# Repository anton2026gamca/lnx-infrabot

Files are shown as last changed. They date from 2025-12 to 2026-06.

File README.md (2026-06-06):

# LNX InfraBot

An autonomous soccer robot for **RoboCup Junior** (Infrared/IR version) that seamlessly integrates hardware control and computer vision. The system uses a Raspberry Pi for advanced vision processing and control logic, while a Teensy microcontroller manages real-time motor and sensor operations.

---

## Project Overview

**LNX-InfraBot** is a competition-ready robot featuring:

- **RoboCup Junior Compliance**: Designed for the Infrared competition category
- **Advanced Computer Vision**: Real-time image processing with OpenCV and NumPy for ball and goal detection
- **Robust Hardware Control**: Motor and sensor integration via Teensy microcontroller
- **Web Dashboard Integration**: Seamless connection with [lnx-dashboard](https://github.com/anton2026gamca/lnx-dashboard) for calibration, remote monitoring, and control
- **Reliable Serial Communication**: High-speed protocol between Raspberry Pi and Teensy

---

## Hardware Components

### Raspberry Pi
- Runs main control software (Python)
- Interfaces with PiCamera2 for vision input
- Hosts FastAPI web server
- Communicates with Teensy via serial connection

### Teensy Microcontroller
- Real-time motor and sensor control
- Manual control switches and status LEDs
- High-speed serial communication (84 kbaud, targeting 120 messages/second)

### 3D Printed Components
- Custom chassis and parts (see `hardware/3D design/`)

---

## Project Structure

```
lnx-infrabot/
├── raspberrypi/             # Raspberry Pi software
│   ├── main.py              # Entry point
│   ├── requirements.txt     # Python dependencies
│   ├── robot.service        # Systemd service file
│   └── robot/               # Main robot package
│       ├── config.py        # Configuration management
│       ├── robot.py         # Core robot control
│       ├── api/             # FastAPI web server
│       ├── hardware/        # Hardware interfaces
│       ├── vision/          # Computer vision processing
│       ├── logic/           # Control logic and algorithms
│       ├── calibration/     # Calibration utilities
│       ├── multiprocessing/ # Concurrent process management
│       └── utils/           # Utility functions
├── teensy/                  # Teensy firmware
│   ├── teensy.ino           # Main Teensy sketch
│   ├── sketch.yaml          # Arduino sketch configuration
│   ├── structures.txt       # Data structure definitions
│   └── test_programs/       # Testing utilities
├── hardware/                # Hardware designs and documentation
│   └── 3D design/           # 3D printable robot parts
├── CONTRIBUTING.md          # Contribution guidelines
└── README.md                # This file
```

---

## Installation

### Raspberry Pi Setup

- **Prerequisites:**
    - **Raspberry Pi 5** with **Raspberry Pi OS Lite** installed

1. **Configure UART, I2C and Camera**  
   Edit `/boot/firmware/config.txt` using a text editor like `nano`:
   ```sh
   sudo nano /boot/firmware/config.txt
   ```
   Add or update the following lines:
   ```txt
   # UART 
   dtoverlay=uart0-pi5

   # Camera
   camera_auto_detect=0
   dtoverlay=imx708,cam0
   dtoverlay=imx708,cam1
   ```
   After editing, press `Ctrl+X` and then `Y` to exit and save.

   Enable I2C:
   ```bash
   sudo raspi-config
   ```
   Go to `Interface Options` -> `I2C`, select `Yes` and press `Enter`

   ```bash
   sudo reboot
   ```

   For more info about the camera, see the [official documentation](https://docs.arducam.com/Raspberry-Pi-Camera/Native-camera/12MP-IMX708/#software-configuration)

2. **Install Dependencies**
   ```bash
   sudo apt update
   sudo apt install git python3.13-dev libcap-dev libgl1 libcamera-apps python3-libcamera i2c-tools python3-gpiozero python3-lgpio
   sudo apt install python3-picamera2 --no-install-recommends
   ```

3. **Clone the Repository**
   ```bash
   git clone --no-checkout https://github.com/anton2026gamca/lnx-infrabot
   cd lnx-infrabot
   git sparse-checkout init --cone
   git sparse-checkout set raspberrypi
   git checkout main
   ```

4. **Set Up Python Virtual Environment**
   ```bash
   cd raspberrypi
   python3 -m venv --system-site-packages .venv
   source .venv/bin/activate
   ```

5. **Install Python Dependencies**
   ```bash
   pip install -r requirements.txt
    ```

6. **Set Environment Variables**
   Create a `.env` file:
   ```
   AUTH_TOKEN=your-secure-token     # Defaults to `ooops` if not set
   ```

7. **Enable Auto-Start**
   ```bash
   sudo ln -s "$(pwd)/robot.service" /etc/systemd/system/
   sudo systemctl daemon-reload
   sudo systemctl enable robot
   sudo systemctl start robot
   ```

### Teensy Setup

1. Open `teensy/teensy.ino` in Arduino IDE
2. Install library dependency: **teensy4_i2c** by Richard Gemmell
3. Select Board: **Teensy 4.1**
4. Upload the sketch to your Teensy board

---

## Usage

### Web API & Dashboard

The robot exposes a FastAPI web server with WebSocket support for real-time communication.

Connect using the [lnx-dashboard](https://github.com/anton2026gamca/lnx-dashboard) for:
- Live camera feed with vision overlays
- Robot telemetry (motion, sensor data)
- Manual and autonomous control

---

## Contributing

See [CONTRIBUTING.md](CONTRIBUTING.md)

---

## Related Projects

- [lnx-dashboard](https://github.com/anton2026gamca/lnx-dashboard) — Web-based monitoring and control dashboard for LNX-InfraBot

---

## RoboCup Junior Information

LNX-InfraBot is designed for the **RoboCup Junior Soccer - Infrared (IR) League**. Learn more:
- [Official RoboCup Website](https://www.robocup.org/)

---

## License

See [LICENSE](LICENSE)

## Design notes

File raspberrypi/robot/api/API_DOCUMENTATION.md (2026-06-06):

# Robot API Documentation

## Overview

This is a comprehensive WebSocket/HTTP API for controlling and monitoring a robot with vision capabilities. The API uses **SocketIO** for real-time bidirectional communication and **FastAPI** as the HTTP server.

**Server Details:**
- Protocol: SocketIO (WebSocket with fallback)
- Authentication: Token-based (base64 encoded) via query parameter
- Max HTTP Buffer Size: 5 MB
- CORS: Enabled for all origins

---

## Table of Contents

1. [Authentication](#authentication)
2. [Real-time Events (Subscriptions)](#real-time-events-subscriptions)
3. [Sensor & State Queries](#sensor--state-queries)
4. [Robot Control (Mutations)](#robot-control-mutations)
5. [Calibration Procedures](#calibration-procedures)
6. [Bluetooth Communication](#bluetooth-communication)
7. [Video Streaming](#video-streaming)
8. [Profiling & Performance](#profiling--performance)

---

## Authentication

All WebSocket connections require authentication via a token passed in the query string:

```
ws://host:port/socket.io/?token=<BASE64_ENCODED_TOKEN>
```

The token is base64-encoded from the configured `AUTH_TOKEN`. If authentication fails, the connection is rejected with a log warning.

---

## Real-time Events (Subscriptions)

### `subscribe_updates`

Subscribe to state change notifications.

**Request:**
```typescript
{
  event: "subscribe_updates",
  data: {
    updates: {
      mode_changed?: boolean,
      goal_color_changed?: boolean,
      important_sensor_data_change?: boolean,
      new_logs?: boolean
    }
  }
}
```

**Response:**
```typescript
{
  status: "ok" | "error",
  message?: string,
  error?: string
}
```

**Emitted Events:**

**`mode_changed`** - Robot mode has changed
```typescript
{
  mode: "idle" | "manual" | "autonomous"
}
```

**`goal_color_changed`** - Target goal color changed
```typescript
{
  goal_color: "yellow" | "blue"
}
```

**`important_sensor_data_change`** - Critical sensor state changed (line, IR, or camera ball detection)
```typescript
{
  status: "ok",
  compass: {
    heading: number,
    pitch: number,
    roll: number
  },
  ir: {
    angle: number,
    distance: number,
    sensors: number[],
    status: string
  },
  camera_ball: {
    angle: number | null,
    distance: number | null,
    detected: boolean | null
  },
  line: {
    raw: number[],
    detected: boolean,
    thresholds: [[number, number], ...]
  },
  motors: {
    left: number,
    right: number
  },
  kicker: {
    charged: boolean,
    ready: boolean
  },
  running_state: {
    running: boolean,
    bt_module_enabled: boolean,
    bt_module_state: boolean,
    switch_state: boolean
  } | null,
  timestamp: number
}
```

**`new_logs`** - New log entries available
```typescript
{
  logs: Array<{
    id: number,
    level: string,
    message: string,
    timestamp: number
  }>
}
```

### `unsubscribe_updates`

Unsubscribe from all state change notifications.

**Request:**
```typescript
{
  event: "unsubscribe_updates",
  data: {}
}
```

**Response:**
```typescript
{
  status: "ok"
}
```

---

## Sensor & State Queries

### `get_sensor_data`

Get current sensor readings and hardware state.

**Request:**
```typescript
{
  event: "get_sensor_data",
  data: {}
}
```

**Response:**
```typescript
{
  status: "ok",
  compass: {
    heading: number,
    pitch: number,
    roll: number
  },
  ir: {
    angle: number,
    distance: number,
    sensors: number[],
    status: string
  },
  camera_ball: {
    angle: number | null,
    distance: number | null,
    detected: boolean | null
  },
  line: {
    raw: number[],
    detected: boolean,
    thresholds: [[number, number], ...]
  },
  motors: {
    left: number,
    right: number
  },
  kicker: {
    charged: boolean,
    ready: boolean
  },
  running_state: {
    running: boolean,
    bt_module_enabled: boolean,
    bt_module_state: boolean,
    switch_state: boolean
  } | null,
  timestamp: number
}
```

### `get_logs`

Retrieve log entries since a specific ID.

**Request:**
```typescript
{
  event: "get_logs",
  data: {
    since?: number  // Log ID to retrieve logs after (default: 0)
  }
}
```

**Response:**
```typescript
{
  status: "ok",
  logs: Array<{
    id: number,
    level: string,
    message: string,
    timestamp: number
  }>,
  last_id: number
}
```

### `get_mode`

Get current robot operation mode.

**Request:**
```typescript
{
  event: "get_mode",
  data: {}
}
```

**Response:**
```typescript
{
  status: "ok",
  mode: "idle" | "manual" | "autonomous"
}
```

### `get_motor_settings`

Get current motor control settings.

**Request:**
```typescript
{
  event: "get_motor_settings",
  data: {}
}
```

**Response:**
```typescript
{
  status: "ok",
  rotation_correction_enabled: boolean,
  line_avoiding_enabled: boolean,
  position_based_speed_enabled: boolean
}
```

### `get_goal_settings`

Get goal detection color and calibration ranges.

**Request:**
```typescript
{
  event: "get_goal_settings",
  data: {}
}
```

**Response:**
```typescript
{
  status: "ok",
  goal_color: "yellow" | "blue",
}
```

### `get_goal_color_calibration`

Get goal color calibration ranges used for goal detection.

**Request:**
```typescript
{
  event: "get_goal_color_calibration",
  data: {
    camera: "front" | "back"
  }
}
```

**Response:**
```typescript
{
  status: "ok"
  yellow_ranges: Array<{
    lower: [number, number, number],  // [H, S, V]
    upper: [number, number, number]   // [H, S, V]
  }>
  blue_ranges: Array<{
    lower: [number, number, number],  // [H, S, V]
    upper: [number, number, number]   // [H, S, V]
  }>
}
```

**HSV Range:**
- **H (Hue):** 0-179
- **S (Saturation):** 0-255
- **V (Value):** 0-255

### `get_goal_detection`

Get current goal detection result.

**Request:**
```typescript
{
  event: "get_goal_detection",
  data: {}
}
```

**Response:**
```typescript
{
  status: "ok",
  goal_detected: boolean,
  alignment: number,           // -1.0 to 1.0 (center alignment)
  goal_center_x: number | null,
  goal_area: number,
  distance_mm: number | null,  // may be null if not available
  goal_height_pixels: number,
  camera_yaw_deg: number,
  goals_by_color: {
    yellow: {
      goal_detected: boolean,
      alignment: number,
      goal_center_x: number | null,
      goal_area: number,
      distance_mm: number | null,
      goal_height_pixels: number,
      camera_yaw_deg: number,
    },
    blue: {
      goal_detected: boolean,
      alignment: number,
      goal_center_x: number | null,
      goal_area: number,
      distance_mm: number | null,
      goal_height_pixels: number,
      camera_yaw_deg: number,
    }
  },
  enemy_goal_color: "yellow" | "blue",
  own_goal_color: "yellow" | "blue",
}
```

### `get_position_estimate`

Get estimated robot position on the field.

**Request:**
```typescript
{
  event: "get_position_estimate",
  data: {}
}
```

**Response:**
```typescript
{
  status: "ok",
  x_mm: number | null,
  y_mm: number | null,
  confidence: number  // 0.0 to 1.0
}
```

### `get_detections`

Get detected objects, optionally filtered by camera.

**Request:**
```typescript
{
  event: "get_detections",
  data: {
    camera?: "front" | "back" | "both" // Default: "both"
  }
}
```

**Response:**
```typescript
{
  status: "ok",
  camera: "front" | "back" | "both",
  detections: {
    front?: Array<{
      object_type: string,
      x: number,
      y: number,
      width: number,
      height: number,
      confidence: number,
      color: [number, number, number], // [B, G, R]
      camera: "front" | "back" | null
    }>,
    back?: Array<{
      object_type: string,
      x: number,
      y: number,
      width: number,
      height: number,
      confidence: number,
      color: [number, number, number], // [B, G, R]
      camera: "front" | "back" | null
    }>
  }
}
```

### `get_ball_calibration`

Get current ball color calibration ranges.

**Request:**
```typescript
{
  event: "get_ball_calibration",
  data: {
    camera?: "front" | "back" // Default: "front"
  }
}
```

**Response:**
```typescript
{
  status: "ok",
  camera: "front" | "back",
  ranges: Array<{
    lower: [number, number, number],  // [H, S, V]
    upper: [number, number, number]   // [H, S, V]
  }>
}
```

### `get_goal_focal_length`

Get the focal length used for distance calculations.

**Request:**
```typescript
{
  event: "get_goal_focal_length",
  data: {
    camera?: "front" | "back" // Default: "front"
  }
}
```

**Response:**
```typescript
{
  status: "ok",
  camera: "front" | "back",
  focal_length_pixels: number
}
```

### `get_camera_settings`

Get current manual camera control values (persisted calibration values).

**Request:**
```typescript
{
  event: "get_camera_settings",
  data: {
    camera?: "front" | "back" | "both" // Default: "both"
  }
}
```

**Response:**
```typescript
{
  status: "ok",
  camera: "front" | "back" | "both",
  settings: {
    front?: {
      camera: "front",
      color_gains: [number, number], // [red_gain, blue_gain]
      exposure_time: number,          // microseconds
      analogue_gain: number
    },
    back?: {
      camera: "back",
      color_gains: [number, number], // [red_gain, blue_gain]
      exposure_time: number,          // microseconds
      analogue_gain: number
    }
  } | {
    camera: "front" | "back",
    color_gains: [number, number], // [red_gain, blue_gain]
    exposure_time: number,          // microseconds
    analogue_gain: number
  }
}
```

### `get_all_state_machines`

Get list of available autonomous state machines.

**Request:**
```typescript
{
  event: "get_all_state_machines",
  data: {}
}
```

**Response:**
```typescript
{
  status: "ok",
  state_machines: string[]
}
```

### `get_autonomous_state`

Get current autonomous mode settings.

**Request:**
```typescript
{
  event: "get_autonomous_state",
  data: {}
}
```

**Response:**
```typescript
{
  status: "ok",
  state_machine: string | null,
  always_face_goal_enabled: boolean,
  camera_ball_usage_enabled: boolean
}
```

### `get_line_calibration_status`

Get current line calibration status.

**Request:**
```typescript
{
  event: "get_line_calibration_status",
  data: {}
}
```

**Response:**
```typescript
{
  status: "ok",
  active: boolean,                         // true when calibration is running
  phase: number,                           // 0 = idle, 1 = phase 1, 2 = phase 2
  current_thresholds: Array<[number, number]>,
  calibration_min: Array<number | null> | null,   // current phase min values
  calibration_max: Array<number | null> | null,   // current phase max values
  phase1_complete: boolean,
  phase1_min: Array<number | null> | null,
  phase1_max: Array<number | null> | null,
  phase2_complete: boolean,
  phase2_min: Array<number | null> | null,
  phase2_max: Array<number | null> | null
}
```

### `get_goal_distance_calibration_status`

Get goal distance calibration status.

**Request:**
```typescript
{
  event: "get_goal_distance_calibration_status",
  data: {}
}
```

**Response:**
```typescript
{
  status: "ok",
  active: boolean,
  phase?: "initial" | "driving",
  initial_distance_mm?: number,
  line_distance_mm?: number,
  initial_height_pixels?: number | null,
  line_height_pixels?: number | null,
  camera?: "front" | "back"
}
```

---

## Robot Control (Mutations)

### `set_mode`

Change robot operation mode.

**Request:**
```typescript
{
  event: "set_mode",
  data: {
    mode: "idle" | "manual" | "autonomous"
  }
}
```

**Response:**
```typescript
{
  status: "ok" | "error",
  error?: string
}
```

### `set_manual_control`

Send manual movement and rotation commands.

**Request:**
```typescript
{
  event: "set_manual_control",
  data: {
    move: {
      angle: number,    // Direction angle in degrees (0-360)
      speed: number     // Speed percentage (0-100)
    },
    rotate: number      // Rotation speed (-100 to 100)
  }
}
```

**Response:**
```typescript
{
  status: "ok" | "error",
  error?: string
}
```

### `reset_compass`

Reset compass heading to 0 degrees.

**Request:**
```typescript
{
  event: "reset_compass",
  data: {}
}
```

**Response:**
```typescript
{
  status: "ok" | "error",
  error?: string
}
```

### `set_motor_settings`

Update motor control settings.

**Request:**
```typescript
{
  event: "set_motor_settings",
  data: {
    rotation_correction_enabled?: boolean,
    line_avoiding_enabled?: boolean,
    position_based_speed_enabled?: boolean
  }
}
```

**Response:**
```typescript
{
  status: "ok" | "error",
  error?: string
}
```

### `set_goal_settings`

Update goal settings

**Request:**
```typescript
{
  event: "set_goal_settings",
  data: {
    goal_color?: "yellow" | "blue",
  }
}
```

**Response:**
```typescript
{
  status: "ok" | "error",
  error?: string
}
```

### `set_goal_color_calibration`

Update goal color calibration ranges

**Request:**
```typescript
{
  event: "set_goal_color_calibration"
  camera: "front" | "back" | "both"
  yellow_ranges?: Array<{
    lower: [number, number, number],  // [H, S, V]
    upper: [number, number, number]
  }>
  blue_ranges?: Array<{
    lower: [number, number, number],
    upper: [number, number, number]
  }>
}
```

**Response:**
```typescript
{
  status: "ok" | "error",
  error?: string
}
```

### `set_ball_calibration`

Update ball color calibration ranges.

**Request:**
```typescript
{
  event: "set_ball_calibration",
  data: {
    camera?: "front" | "back" | "both", // Default: "both"
    ranges: Array<{
      lower: [number, number, number],  // [H, S, V]
      upper: [number, number, number]
    }>
  }
}
```

**Response:**
```typescript
{
  status: "ok" | "error",
  error?: string
}
```

### `set_goal_focal_length`

Set the focal length for goal distance calculations.

**Request:**
```typescript
{
  event: "set_goal_focal_length",
  data: {
    focal_length_pixels: number,  // Must be positive
    camera?: "front" | "back" | "both" // Default: "both"
  }
}
```

**Response:**
```typescript
{
  status: "ok" | "error",
  focal_length_pixels?: number,
  error?: string
}
```

### `set_camera_settings`

Manually set camera control values and apply them immediately. These values are persisted to calibration storage.

**Request:**
```typescript
{
  event: "set_camera_settings",
  data: {
    camera?: "front" | "back" | "both", // Default: "both"
    color_gains?: [number, number],     // [red_gain, blue_gain], positive values
    exposure_time?: number,             // microseconds, positive
    analogue_gain?: number              // positive
  }
}
```

**Note:** Provide at least one of `color_gains`, `exposure_time`, or `analogue_gain`.

**Response:**
```typescript
{
  status: "ok" | "error",
  camera?: "front" | "back" | "both",
  settings?: {
    front?: {
      camera: "front",
      color_gains: [number, number],
      exposure_time: number,
      analogue_gain: number
    },
    back?: {
      camera: "back",
      color_gains: [number, number],
      exposure_time: number,
      analogue_gain: number
    }
  },
  error?: string
}
```

### `set_autonomous_state`

Configure autonomous mode settings.

**Request:**
```typescript
{
  event: "set_autonomous_state",
  data: {
    state_machine?: string,
    always_face_goal_enabled?: boolean,
    camera_ball_usage_enabled?: boolean
  }
}
```

**Response:**
```typescript
{
  status: "ok" | "error",
  error?: string
}
```

### `set_line_thresholds`

Set line sensor detection thresholds.

**Request:**
```typescript
{
  event: "set_line_thresholds",
  data: {
    thresholds: Array<[number, number]>  // [min, max] for each line sensor
  }
}
```

**Note:** The `thresholds` array must have exactly `LINE_SENSOR_COUNT` pairs.

**Response:**
```typescript
{
  status: "ok" | "error",
  thresholds?: Array<[number, number]>,
  error?: string
}
```

---

## Calibration Procedures

### `camera_ball_distance_calibration`

Calibrate ball distance detection. Place ball at a known distance and call this endpoint.

**Request:**
```typescript
{
  event: "camera_ball_distance_calibration",
  data: {
    known_distance_mm: number,  // Distance from camera to ball in millimeters
    camera?: "front" | "back"   // Default: "front"
  }
}
```

**Response:**
```typescript
{
  status: "ok" | "error",
  calibration_constant?: number,
  error?: string
}
```

### `camera_auto_calibration`

Temporarily enable camera AWB and AE so the camera can adapt to current lighting, then disable both again and copy the learned values to all other cameras. The resulting gains/exposure values are also saved to calibration storage.

**Request:**
```typescript
{
  event: "camera_auto_calibration",
  data: {
    camera?: "front" | "back", // Default: "front"
    settle_time_s?: number              // Seconds to keep AWB/AE enabled (default: 2.0)
  }
}
```

**Response:**
```typescript
{
  status: "ok" | "error",
  camera?: "front" | "back" | "both",
  result?: {
    color_gains: [number, number],    // [red_gain, blue_gain]
    exposure_time: number | null,     // microseconds
    analogue_gain: number | null,
    settle_time_s: number
  },
  error?: string
}
```

### `add_goal_color_range`

Add a new HSV range for goal color detection.

**Request:**
```typescript
{
  event: "add_goal_color_range",
  data: {
    goal_color: "yellow" | "blue",
    lower: [number, number, number],  // [H, S, V]
    upper: [number, number, number],  // [H, S, V]
    camera?: "front" | "back" | "both" // Default: "both"
  }
}
```

**Response:**
```typescript
{
  status: "ok" | "error",
  ranges?: Array<{
    lower: [number, number, number],
    upper: [number, number, number]
  }>,
  error?: string
}
```

### `remove_goal_color_range`

Remove a goal color range by index.

**Request:**
```typescript
{
  event: "remove_goal_color_range",
  data: {
    goal_color: "yellow" | "blue",
    index: number,  // Index of the range to remove
    camera?: "front" | "back" | "both" // Default: "both"
  }
}
```

**Response:**
```typescript
{
  status: "ok" | "error",
  ranges?: Array<{
    lower: [number, number, number],
    upper: [number, number, number]
  }>,
  error?: string
}
```

### `add_ball_color_range`

Add a new HSV range for ball color detection.

**Request:**
```typescript
{
  event: "add_ball_color_range",
  data: {
    lower: [number, number, number],  // [H, S, V]
    upper: [number, number, number],  // [H, S, V]
    camera?: "front" | "back" | "both" // Default: "both"
  }
}
```

**Response:**
```typescript
{
  status: "ok" | "error",
  ranges?: Array<{
    lower: [number, number, number],
    upper: [number, number, number]
  }>,
  error?: string
}
```

### `remove_ball_color_range`

Remove a ball color range by index.

**Request:**
```typescript
{
  event: "remove_ball_color_range",
  data: {
    index: number,  // Index of the range to remove
    camera?: "front" | "back" | "both" // Default: "both"
  }
}
```

**Response:**
```typescript
{
  status: "ok" | "error",
  ranges?: Array<{
    lower: [number, number, number],
    upper: [number, number, number]
  }>,
  error?: string
}
```

### `start_line_calibration`

Begin line sensor calibration.

**Request:**
```typescript
{
  event: "start_line_calibration",
  data: {
    phase: 1 | 2  // Calibration phase (default: 1)
  }
}
```

**Response:**
```typescript
{
  status: "ok" | "error",
  phase?: number,
  message?: string,
  error?: string
}
```

**Phases:**
- **Phase 1:** Calibrate with white area
- **Phase 2:** Calibrate with black line

### `stop_line_calibration`

Stop line calibration and apply learned thresholds.

**Request:**
```typescript
{
  event: "stop_line_calibration",
  data: {}
}
```

**Response:**
```typescript
{
  status: "ok" | "error",
  phase?: number,
  thresholds?: Array<[number, number]>,
  min_values?: number[],
  max_values?: number[],
  can_start_phase2?: boolean,
  error?: string
}
```

### `cancel_line_calibration`

Cancel ongoing line calibration without applying changes.

**Request:**
```typescript
{
  event: "cancel_line_calibration",
  data: {}
}
```

**Response:**
```typescript
{
  status: "ok" | "error",
  phase?: number,
  message?: string,
  error?: string
}
```

### `start_goal_distance_calibration`

Begin goal distance calibration. Drive robot toward goal until it hits the line.

**Request:**
```typescript
{
  event: "start_goal_distance_calibration",
  data: {
    initial_distance?: number,  // Initial distance in mm (default: 200)
    line_distance?: number,     // Expected line distance in mm (default: 200)
    camera?: "front" | "back"   // Default: "front"
  }
}
```

**Response:**
```typescript
{
  status: "ok" | "error",
  message?: string,
  error?: string
}
```

### `stop_goal_distance_calibration`

Stop goal distance calibration and save results.

**Request:**
```typescript
{
  event: "stop_goal_distance_calibration",
  data: {}
}
```

**Response:**
```typescript
{
  status: "ok" | "error",
  focal_length_pixels?: number,
  camera?: "front" | "back",
  message?: string,
  error?: string
}
```

### `cancel_goal_distance_calibration`

Cancel goal distance calibration without saving.

**Request:**
```typescript
{
  event: "cancel_goal_distance_calibration",
  data: {}
}
```

**Response:**
```typescript
{
  status: "ok" | "error",
  message?: string,
  error?: string
}
```

### `compute_hsv_from_regions`

Analyze selected image regions and compute HSV ranges.

**Request:**
```typescript
{
  event: "compute_hsv_from_regions",
  data: {
    camera?: "front" | "back",  // Default: "front"
    regions: Array<{
      x: number,       // X coordinate
      y: number,       // Y coordinate
      width: number,   // Region width in pixels
      height: number   // Region height in pixels
    }>
  }
}
```

**Response:**
```typescript
{
  status: "ok" | "error",
  lower?: [number, number, number],   // [H, S, V] minimum
  upper?: [number, number, number],   // [H, S, V] maximum
  error?: string
}
```

**Algorithm:**
- Extracts HSV values from all specified regions
- Computes 5th-95th percentile with margins:
  - Hue: ±5
  - Saturation: ±20
  - Value: ±20
- Returns union of all regions

---

## Bluetooth Communication

Bluetooth is handled by a dedicated background process. The API exposes state and messaging helpers for robot-to-robot communication.

### `get_bluetooth_state`

Get Bluetooth process status, local device identity, connected devices, paired devices, and selected peer robot metadata.

**Request:**
```typescript
{
  event: "get_bluetooth_state",
  data: {}
}
```

**Response:**
```typescript
{
  status: "ok",
  bluetooth_enabled: boolean,
  process_alive: boolean,
  local_device: {
    mac_address?: string,
    hostname?: string,
    ip_address?: string
  },
  connected_devices: Array<{
    name: string,
    mac_address: string,
    connected: boolean,
    last_seen?: number
  }>,
  paired_devices: Array<{
    name: string,
    mac_address: string,
    connected: boolean,
    last_seen?: number
  }>,
  other_robot: {
    mac_address?: string,
    name?: string,
    hostname?: string,
    ip_address?: string,
    note?: string
  }
}
```

### `set_bluetooth_enabled`

Enable or disable Bluetooth usage. When disabled, auto-connect is paused and active connections are closed.

**Request:**
```typescript
{
  event: "set_bluetooth_enabled",
  data: {
    enabled: boolean
  }
}
```

**Response:**
```typescript
{
  status: "ok" | "error",
  bluetooth_enabled?: boolean,
  error?: string
}
```

### `set_other_robot`

Set or clear metadata for the selected "other robot".

**Request (set):**
```typescript
{
  event: "set_other_robot",
  data: {
    mac_address: string,
    name?: string,
    hostname?: string,
    ip_address?: string,
    note?: string
  }
}
```

**Request (clear):**
```typescript
{
  event: "set_other_robot",
  data: {
    clear: true
  }
}
```

**Response:**
```typescript
{
  status: "ok" | "error",
  other_robot?: {
    mac_address?: string,
    name?: string,
    hostname?: string,
    ip_address?: string,
    note?: string
  },
  error?: string
}
```

**Notes:**
- `mac_address` is normalized to uppercase when stored.

### `bluetooth_connect_other_robot`

Connect to the selected robot (or explicit `mac_address`).

**Request:**
```typescript
{
  event: "bluetooth_connect_other_robot",
  data: {
    mac_address?: string
  }
}
```

**Response:**
```typescript
{
  status: "ok" | "error",
  result?: {
    command_id: number,
    success: boolean,
    data: object,
    error?: string,
    timestamp: number
  },
  connected_devices?: object[],
  error?: string
}
```

### `bluetooth_disconnect_other_robot`

Disconnect from the selected robot (or explicit `mac_address`).

**Request:**
```typescript
{
  event: "bluetooth_disconnect_other_robot",
  data: {
    mac_address?: string
  }
}
```

**Response:**
```typescript
{
  status: "ok" | "error",
  result?: {
    command_id: number,
    success: boolean,
    data: object,
    error?: string,
    timestamp: number
  },
  connected_devices?: object[],
  error?: string
}
```

### `bluetooth_send_message`

Send a custom Bluetooth message to the selected robot or an explicit `mac_address`.

**Request:**
```typescript
{
  event: "bluetooth_send_message",
  data: {
    mac_address?: string,
    message_type: string,
    content: string,
    sender_id?: string
  }
}
```

**Response:**
```typescript
{
  status: "ok" | "error",
  result?: {
    command_id: number,
    success: boolean,
    data: {
      mac_address: string,
      message_id: string
    },
    error?: string,
    timestamp: number
  },
  error?: string
}
```

**Notes:**
- `sender_id` is optional. If omitted, sent messages use the local robot hostname as sender ID.
- Received messages always include `sender_mac`; if no `sender_id` was provided by the sender, it is filled with `sender_mac`.

### `get_bluetooth_messages`

Get sent and received Bluetooth message history.

**Request:**
```typescript
{
  event: "get_bluetooth_messages",
  data: {
    clear?: boolean, // default false
    limit?: number   // optional last N messages
  }
}
```

**Response:**
```typescript
{
  status: "ok",
  received: Array<{
    message_type: string,
    content: string,
    sender_id?: string,
    sender_mac?: string,
    timestamp?: number,
    message_id?: string
  }>,
  sent: Array<{
    message_type: string,
    content: string,
    sender_id?: string,
    target_mac?: string,
    timestamp?: number,
    message_id?: string
  }>
}
```

### `bluetooth_list_pairable_devices`

List nearby discoverable Bluetooth devices that are available for pairing.

**Request:**
```typescript
{
  event: "bluetooth_list_pairable_devices",
  data: {
    timeout_seconds?: number  // Scan duration in seconds (default: 6, must be > 0)
  }
}
```

**Response:**
```typescript
{
  status: "ok" | "error",
  result?: {
    command_id: number,
    success: boolean,
    data: object,
    error?: string,
    timestamp: number
  },
  devices?: Array<{
    name: string,
    mac_address: string,
    connected: boolean,
    last_seen?: number
  }>,
  error?: string
}
```

**Notes:**
- Requires `bluetoothctl` and sufficient permissions on the Raspberry Pi
- `timeout_seconds` controls how long active discovery runs before returning results
- `devices` are normalized to the same shape as paired/connected device entries

### `bluetooth_pair_device`

Pair a new Bluetooth device and store its metadata.

**Request:**
```typescript
{
  event: "bluetooth_pair_device",
  data: {
    mac_address: string,
  }
}
```

**Response:**
```typescript
{
  status: "ok" | "error",
  result?: {
    command_id: number,
    success: boolean,
    data: object,
    error?: string,
    timestamp: number
  },
  paired_devices?: Array<{
    name: string,
    mac_address: string,
    connected: boolean,
    last_seen?: number
  }>,
  error?: string
}
```

### `bluetooth_unpair_device`

Unpair a previously paired Bluetooth device.

**Request:**
```typescript
{
  event: "bluetooth_unpair_device",
  data: {
    mac_address: string
  }
}
```

**Response:**
```typescript
{
  status: "ok" | "error",
  result?: {
    command_id: number,
    success: boolean,
    data: object,
    error?: string,
    timestamp: number
  },
  paired_devices?: Array<{
    name: string,
    mac_address: string,
    connected: boolean,
    last_seen?: number
  }>,
  error?: string
}
```

### `set_bluetooth_pairing_mode`

Set Bluetooth pairing mode (enable or disable discoverability).

**Request:**
```typescript
{
  event: "set_bluetooth_pairing_mode",
  data: {
    enabled: boolean  // true to enable pairing mode, false to disable
  }
}
```

**Response:**
```typescript
{
  status: "ok" | "error",
  result?: {
    command_id: number,
    success: boolean,
    data: {
      pairing_mode_enabled: boolean
    },
    error?: string,
    timestamp: number
  },
  pairing_mode_enabled?: boolean,
  error?: string
}
```

---

## Video Streaming

### `subscribe_video`

Start receiving video frames from the robot cameras.

**Request:**
```typescript
{
  event: "subscribe_video",
  data: {
    fps?: number,              // Frames per second (default from config)
    show_detections?: boolean, // Overlay detection boxes on the streamed camera(s) (default: true)
    camera?: "front" | "back" | "both" // Default: "both"
  }
}
```

**Response:**
```typescript
{
  status: "ok" | "error",
  message?: string,
  error?: string
}
```

**Emitted Events:**

**`video_frame_front`** - Binary JPEG frame data from the front camera
```typescript
<bytes>  // Raw JPEG image data
```

**`video_frame_back`** - Binary JPEG frame data from the back camera
```typescript
<bytes>  // Raw JPEG image data
```

When `camera: "both"` is used, the server emits both `video_frame_front` and `video_frame_back`.

### `unsubscribe_video`

Stop receiving video frames.

**Request:**
```typescript
{
  event: "unsubscribe_video",
  data: {}
}
```

**Response:**
```typescript
{
  status: "ok" | "error",
  error?: string
}
```

---

## Profiling & Performance

The API provides real-time control over profiling data collection. Profiling tracks function execution times, lock contention, and process metrics across all robot processes. Use the profiling endpoints to enable/disable collection at runtime, retrieve performance metrics, and analyze bottlenecks.

### `profiling_start`

Start collecting profiling data.

**Request:**
```typescript
{
  event: "profiling_start",
  data: {}
}
```

**Response:**
```typescript
{
  status: "ok" | "error",
  message: string,
  error?: string
}
```

**Description:** Initializes the profiling collector and begins recording function execution times, lock contention events, and process metrics. Previous collected data is cleared when starting a new collection session.

### `profiling_stop`

Stop collecting profiling data without clearing accumulated data.

**Request:**
```typescript
{
  event: "profiling_stop",
  data: {}
}
```

**Response:**
```typescript
{
  status: "ok" | "error",
  message: string,
  error?: string
}
```

**Description:** Stops the profiler from collecting new events. Data collected so far remains available for retrieval via `profiling_report`.

### `profiling_status`

Get current profiling status and statistics.

**Request:**
```typescript
{
  event: "profiling_status",
  data: {}
}
```

**Response:**
```typescript
{
  status: "ok" | "error",
  is_collecting: boolean,
  total_function_events: number,
  total_lock_events: number,
  total_processes: number,
  collection_duration: number  // seconds
}
```

**Description:** Returns the current profiling state including whether collection is active and basic statistics about collected data.

### `profiling_report`

Get detailed profiling report with metrics and statistics.

**Request:**
```typescript
{
  event: "profiling_report",
  data: {
    include_stack_traces?: boolean  // Default: false (stack traces omitted to reduce network size)
  }
}
```

**Response:**
```typescript
{
  status: "ok" | "error",
  report?: {
    metadata: {
      collection_duration: number,
      start_time: number,
      end_time: number,
      total_function_events: number,
      total_lock_events: number,
      total_processes: number,
      is_collecting: boolean
    },
    processes: {
      [process_name]: {
        process_name: string,
        process_id: number,
        start_time: number,
        stop_time: number,
        function_count: number,
        lock_events_count: number
      }
    },
    functions: {
      by_name: {
        [function_name]: {
          count: number,
          total_time: number,
          min_time: number,
          max_time: number,
          avg_time: number,
          name: string
        }
      },
      sorted_by_total_time: [...]  // Top functions by total execution time
    },
    locks: {
      by_name: {
        [lock_name]: {
          acquire_count: number,
          total_wait_time: number,
          max_wait_time: number,
          contentions: number
        }
      },
      sorted_by_contention: [...]  // Locks sorted by contention count
    },
    timeline: {
      processes: [...],       // Process lifecycle events (max 1000)
      functions: [...],       // Function call events (max 1000)
      locks: [...]            // Lock events (max 1000)
    }
  },
  error?: string
}
```

**Description:** Returns comprehensive profiling data including:
- **Metadata:** Collection duration and event counts
- **Processes:** Per-process statistics and lifecycle
- **Functions:** Execution time statistics for all profiled functions
- **Locks:** Lock contention and wait time statistics
- **Timeline:** Time-series event data

**Data Fields Explanation:**
- `count` - Number of times the event occurred
- `total_time` - Sum of all durations (seconds)
- `avg_time` - Average time per occurrence
- `min_time`, `max_time` - Minimum and maximum durations
- `contentions` - Number of times a lock was contested
- `total_wait_time` - Total time processes waited for this lock
- `max_wait_time` - Maximum single wait duration

### `profiling_clear`

Clear all collected profiling data and reset the collector.

**Request:**
```typescript
{
  event: "profiling_clear",
  data: {}
}
```

**Response:**
```typescript
{
  status: "ok" | "error",
  message: string,
  error?: string
}
```

**Description:** Clears all collected profiling data. After clearing, the profiler remains in its current state (collecting or stopped). Start a new session with `profiling_start` to begin fresh data collection.

---

## Error Responses

All error responses follow this format:

```typescript
{
  status: "error",
  error: string  // Human-readable error message
}
```

Common error scenarios:
- **Invalid authentication:** Connection rejected before handshake
- **Internal server error:** Server-side exception occurred
- **Invalid parameters:** Request data doesn't match expected format
- **Invalid state:** Operation not allowed in current state (e.g., stopping when not started)

---

## Connection Example (JavaScript/TypeScript)

```typescript
import io from 'socket.io-client';

const token = btoa('your_auth_token');  // Base64 encode the token
const socket = io('ws://robot-ip:port', {
  query: {
    token: token
  }
});

socket.on('connect', () => {
  console.log('Connected');
  
  // Subscribe to updates
  socket.emit('subscribe_updates', {
    updates: {
      mode_changed: true,
      important_sensor_data_change: true,
      new_logs: true
    }
  }, (response) => {
    console.log('Subscription response:', response);
  });
  
  // Subscribe to video
  socket.emit('subscribe_video', {
    fps: 30,
    show_detections: true,
    camera: 'both'
  });
});

// Listen for sensor data changes
socket.on('important_sensor_data_change', (data) => {
  console.log('Sensor data changed:', data);
});

socket.on('video_frame_front', (frameData) => {
  // Front camera (binary JPEG data)
  const blob = new Blob([frameData], { type: 'image/jpeg' });
  const url = URL.createObjectURL(blob);
  // Display in <img src={url} /> or canvas
});

socket.on('video_frame_back', (frameData) => {
  // Back camera (binary JPEG data)
  const blob = new Blob([frameData], { type: 'image/jpeg' });
  const url = URL.createObjectURL(blob);
  // Display in <img src={url} /> or canvas
});

socket.on('disconnect', () => {
  console.log('Disconnected');
});
```

---

## Notes

- All timestamps are in seconds (Unix epoch)
- All distances in calibration are in millimeters (mm)
- All angles in degrees (0-360)
- HSV ranges: H (0-179), S (0-255), V (0-255) (OpenCV convention)
- State monitoring interval: 100ms
- Video frames are compressed as JPEG with configured quality
- Disconnected clients are automatically cleaned up after failed emission attempts

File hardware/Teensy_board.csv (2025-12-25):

 |  |  |  |  |  |  |  | USB PORT
 | 12V |  |  |  | 12V |  |  | USB PORT |  |  |  |  | GND
 |  |  |  |  |  |  |  | USB PORT |  | E
 | GND |  |  |  | GND |  |  | USB PORT |  |  | B |  | KICK
 |  |  |  |  |  |  |  | USB PORT |  |  |  |  |  |  |  |  |  |  |  |  | HV4 |  | LV4
 | 12V |  |  |  | 5V |  |  | USB PORT |  |  |  |  |  |  |  |  |  |  |  |  | HV3 |  | LV3
 |  |  |  |  |  |  |  | USB PORT |  |  |  |  |  |  |  |  |  |  |  |  | GND |  | GND
 | GND |  |  |  |  |  |  | USB PORT |  |  |  |  |  |  |  |  |  |  |  |  | HV |  | LV
 |  |  |  |  |  |  |  | USB PORT |  |  |  |  |  |  |  |  |  |  |  |  | HV2 |  | LV2
 | 12V |  |  |  |  |  |  | USB PORT |  |  |  |  |  |  |  |  |  |  |  |  | HV1 |  | LV1
 |  |  |  |  |  |  |  | USB PORT |  |  |  |  |  |  |  |  |  |  |  |  | HV4 |  | LV4
 | GND |  |  |  |  |  |  | USB PORT |  |  |  |  |  |  |  |  |  |  |  |  | HV3 |  | LV3
 |  |  |  |  |  | GND |  |  | 5V | Vin |  |  |  |  |  |  |  |  |  |  | GND |  | GND
 |  |  |  |  |  | 0 |  |  |  | GND |  |  |  |  |  |  |  |  |  |  | HV |  | LV
 |  |  |  |  |  | 1 |  |  |  | 3.3V |  |  |  |  |  |  |  |  |  |  | HV2 |  | LV2
 |  |  |  |  |  | 2 |  |  |  | 23 |  |  | 0 |  |  |  |  |  |  |  | HV1 |  | LV1
 | 1P | HV4 |  | LV4 |  | 3 |  |  |  | 22 |  |  | 1
 | 1D | HV3 |  | LV3 |  | 4 |  |  |  | 21 |  |  | 2
1P |  | GND |  | GND |  | 5 |  |  |  | 20 |  |  | 3
1D |  | HV |  | LV |  | 6 |  |  |  | 19 |  |  | 4
2P | 2P | HV2 |  | LV2 |  | 7 |  |  |  | 18 |  |  | 5
2D | 2D | HV1 |  | LV1 |  | 8 |  |  |  | 17 |  |  | 6
3P | 3P | HV4 |  | LV4 |  | 9 |  |  |  | 16 |  |  | 7
3D | 3D | HV3 |  | LV3 |  | 10 |  |  |  | 15 |  |  | 8
4P |  | GND |  | GND |  | 11 |  |  |  | 14 |  |  | 9
4D |  | HV |  | LV |  | 12 |  |  |  | 13 |  |  | 10 |  | 5V
 | 4P | HV2 |  | LV2 |  | 3.3V |  |  |  | GND |  |  | 11
 | 4D | HV1 |  | LV1 |  | 24 |  |  |  | 41 |  |  | 12 |  | GND
 |  |  |  |  |  | 25 |  |  |  | 40 |  |  | 13
 | 3.3V | 3.3V |  |  |  | 26 |  |  |  | 39 |  |  | 14 |  | 12V
 | GND | GND |  |  |  | 27 |  |  |  | 38 |  |  | 15
 | SCL | SCL |  |  |  | 28 |  |  |  | 37
 | SDA | SDA |  |  |  | 29 |  |  |  | 36
 |  |  |  |  |  | 30 |  |  |  | 35 |  |  | TX
 | 3.3V | 3.3V |  |  |  | 31 |  |  |  | 34 |  |  | RX
 | GND | GND |  |  |  | 32 |  |  |  | 33
 |  |  |  | SW | SW |  |  | SCM
 | 3.3V | 3.3V |  |  |  |  |  | 3.3V
 | GND | GND |  |  |  |  |  | GND
 |  |  |  |  |  |  |  |  |  |  |  |  |  |  |  |  | ak sa pouzije externy menic napatia s low gnd high vstupmi
 | 5V | 5V |  |  |  | GND |  |  | 5V | Vin |  | 5V | 5V |  |  |  | 5V |  |  | GND |  |  | 5V | Vin |  | 5V | 5V
 | GND | GND |  |  |  | 0 |  |  |  | GND |  | GND | GND |  |  |  | GND |  |  | 0 |  |  |  | GND |  | GND | GND
 |  |  |  |  |  | 1 |  |  |  | 3.3V |  |  |  |  |  |  |  |  |  | 1 |  |  |  | 3.3V
 |  |  |  |  |  | 2 |  |  |  | 23 |  |  | 0 |  |  |  |  |  |  | 2 |  |  |  | 23 |  |  | 0
 | 1P | HV4 |  | LV4 |  | 3 |  |  |  | 22 |  |  | 1 |  | 1P | HV4 |  | LV4 |  | 3 |  |  |  | 22 |  |  | 1
 | 1D | HV3 |  | LV3 |  | 4 |  |  |  | 21 |  |  | 2 |  | 1D | HV3 |  | LV3 |  | 4 |  |  |  | 21 |  |  | 2
1P |  | GND |  | GND |  | 5 |  |  |  | 20 |  |  | 3 | 1P |  | GND |  | GND |  | 5 |  |  |  | 20 |  |  | 3
1D |  | HV |  | LV |  | 6 |  |  |  | 19 |  |  | 4 | 1D |  | HV |  | LV |  | 6 |  |  |  | 19 |  |  | 4
2P | 2P | HV2 |  | LV2 |  | 7 |  |  |  | 18 |  |  | 5 | 2P | 2P | HV2 |  | LV2 |  | 7 |  |  |  | 18 |  |  | 5
2D | 2D | HV1 |  | LV1 |  | 8 |  |  |  | 17 |  |  | 6 | 2D | 2D | HV1 |  | LV1 |  | 8 |  |  |  | 17 |  |  | 6
3P | 3P | HV4 |  | LV4 |  | 9 |  |  |  | 16 |  |  | 7 | 3P | 3P | HV4 |  | LV4 |  | 9 |  |  |  | 16 |  |  | 7
3D | 3D | HV3 |  | LV3 |  | 10 |  |  |  | 15 |  |  | 8 | 3D | 3D | HV3 |  | LV3 |  | 10 |  |  |  | 15 |  |  | 8
4P |  | GND |  | GND |  | 11 |  |  |  | 14 |  |  | 9 | 4P |  | GND |  | GND |  | 11 |  |  |  | 14 |  |  | 9
4D |  | HV |  | LV |  | 12 |  |  |  | 13 |  |  | 10 | 4D |  | HV |  | LV |  | 12 |  |  |  | 13 |  |  | 10
 | 4P | HV2 |  | LV2 |  | 3.3V |  |  |  | GND |  |  | 11 |  | 4P | HV2 |  | LV2 |  | 3.3V |  |  |  | GND |  |  | 11
 | 4D | HV1 |  | LV1 |  | 24 |  |  |  | 41 |  |  | 12 |  | 4D | HV1 |  | LV1 |  | 24 |  |  |  | 41 |  |  | 12
 |  |  |  |  |  | 25 |  |  |  | 40 |  |  | 13 |  |  |  |  |  |  | 25 |  |  |  | 40 |  |  | 13
 | 3.3V | 3.3V |  |  |  | 26 |  |  |  | 39 |  |  | 14 |  | 3.3V | 3.3V |  |  |  | 26 |  |  |  | 39 |  |  | 14
 | GND | GND |  |  |  | 27 |  |  |  | 38 |  |  | 15 |  | GND | GND |  |  |  | 27 |  |  |  | 38 |  |  | 15
 | SCL | SCL |  |  |  | 28 |  |  |  | 37 |  |  |  |  | SCL | SCL |  |  |  | 28 |  |  |  | 37
 | SDA | SDA |  |  |  | 29 |  |  |  | 36 |  |  |  |  | SDA | SDA |  |  |  | 29 |  |  |  | 36
 |  |  |  |  |  | 30 |  |  |  | 35 |  |  | TX |  |  |  |  |  |  | 30 |  |  |  | 35 |  |  | TX
 | 3.3V | 3.3V |  |  |  | 31 |  |  |  | 34 |  |  | RX |  | 3.3V | 3.3V |  |  |  | 31 |  |  |  | 34 |  |  | RX
 | GND | GND |  |  |  | 32 |  |  |  | 33 |  |  |  |  | GND | GND |  | SW | SW | 32 |  |  |  | 33 | SCM
 |  |  |  | SW | SW
 | 3.3V | 3.3V
 | GND | GND |  |  |  |  |  |  |  |  |  |  |  |  |  |  |  |  |  |  |  |  |  |  |  |  | 5V
 |  |  |  |  |  |  |  |  |  |  |  |  |  |  | 12V |  |  |  |  |  |  | 5V | GND
 |  |  |  |  |  |  |  |  |  |  |  |  |  |  |  |  |  |  |  |  |  | 5V | GND |  |  |  | GND
 |  |  |  |  |  |  |  |  |  |  |  |  |  |  | GND |  |  |  |  |  |  | 5V | GND
 |  |  |  |  |  |  |  |  |  |  |  |  |  |  |  |  |  |  |  |  |  | 5V | GND |  |  |  | 12V
 |  |  |  |  |  |  |  |  |  |  |  |  |  |  | 12V |  |  |  |  |  |  | 5V | GND
 |  |  |  |  |  |  |  |  |  |  |  |  | O0 |  | GND |  |  |  |  |  |  |  |  |  |  |  | K+
 |  |  |  |  |  |  |  |  |  |  |  |  | O1
 |  |  |  |  |  |  | GND |  |  |  |  |  | RX |  | 12V |  |  |  |  |  |  |  |  |  |  |  | K-
 |  |  | GND |  |  |  | 3.3V |  |  |  |  |  | TX
 |  |  | BAT |  |  |  | LGV |  |  |  |  |  | D+ |  | GND |  |  |  |  |  |  | BAS | COL
 |  |  |  |  |  |  | VIN |  |  |  |  |  | D- |  |  |  |  |  |  |  |  | EM
 | 5V | 5V |  |  |  | GND |  |  | 5V | Vin |  | 5V | 5V
 | GND | GND |  |  |  | 0 |  |  |  | GND |  | GND | GND
 |  |  |  |  |  | 1 |  |  |  | 3.3V
 |  |  |  |  |  | 2 |  |  |  | 23 |  |  | 0
 | 1P | HV4 |  | LV4 |  | 3 |  |  |  | 22 |  |  | 1
 | 1D | HV3 |  | LV3 |  | 4 |  |  |  | 21 |  |  | 2
1P |  | GND |  | GND |  | 5 |  |  |  | 20 |  |  | 3
1D |  | HV |  | LV |  | 6 |  |  |  | 19 |  |  | 4
2P | 2P | HV2 |  | LV2 |  | 7 |  |  |  | 18 |  |  | 5
2D | 2D | HV1 |  | LV1 |  | 8 |  |  |  | 17 |  |  | 6
3P | 3P | HV4 |  | LV4 |  | 9 |  |  |  | 16 |  |  | 7
3D | 3D | HV3 |  | LV3 |  | 10 |  |  |  | 15 |  |  | 8
4P |  | GND |  | GND |  | 11 |  |  |  | 14 |  |  | 9
4D |  | HV |  | LV |  | 12 |  |  |  | 13 |  |  | 10
 | 4P | HV2 |  | LV2 |  | 3.3V |  |  |  | GND |  |  | 11
 | 4D | HV1 |  | LV1 |  | 24 |  |  |  | 41 |  |  | 12
 |  |  |  |  |  | 25 |  |  |  | 40 |  |  | 13
 | 3.3V | 3.3V |  |  |  | 26 |  |  |  | 39 |  |  | 14
 | GND | GND |  |  |  | 27 |  |  |  | 38 |  |  | 15
 | SCL | SCL |  |  |  | 28 |  |  |  | 37
 | SDA | SDA |  |  |  | 29 |  |  |  | 36
 |  |  |  |  |  | 30 |  |  |  | 35 |  |  | TX
 | 3.3V | 3.3V |  |  |  | 31 |  |  |  | 34 |  |  | RX
 | GND | GND |  |  |  | 32 |  |  |  | 33
 |  |  |  | SW | SW |  |  | SCM
 | 3.3V | 3.3V |  |  |  |  |  | 3.3V
 | GND | GND |  |  |  |  |  | GND
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

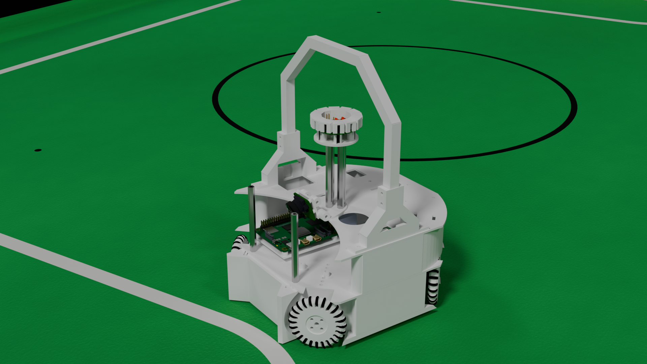
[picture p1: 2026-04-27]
hardware/3d_render/robot_render.png

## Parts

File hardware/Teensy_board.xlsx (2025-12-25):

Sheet: Hárok1
 |  |  |  |  |  |  |  |  |  |  | 5V | 5V | 5V
 |  |  | GND | 5V | Vin |  |  |  |  |  | GND | GND | GND | GND | 5V | Vin
 |  |  | 0 |  | GND |  |  |  |  |  |  |  |  | 0 |  | GND
 |  |  | 1 |  | 3.3V |  |  |  |  |  |  |  |  | 1 |  | 3.3V
 |  |  | 2 |  | 23 | 0 |  |  |  |  |  |  |  | 2 |  | 23 | 0
 | HV4 | LV4 | 3 |  | 22 | 1 |  |  |  | HV4 |  | LV4 |  | 3 |  | 22 | 1
 | HV3 | LV3 | 4 |  | 21 | 2 |  |  |  | HV3 |  | LV3 |  | 4 |  | 21 | 2
P1 | GND | GND | 5 |  | 20 | 3 |  | P1 |  | GND |  | GND |  | 5 |  | 20 | 3
D1 | HV | LV | 6 |  | 19 | 4 |  | D1 |  | HV |  | LV |  | 6 |  | 19 | 4
P2 | HV2 | LV2 | 7 |  | 18 | 5 |  | P2 |  | HV2 |  | LV2 |  | 7 |  | 18 | 5
D2 | HV1 | LV1 | 8 |  | 17 | 6 |  | D2 |  | HV1 |  | LV1 |  | 8 |  | 17 | 6
P3 | HV4 | LV4 | 9 |  | 16 | 7 |  | P3 |  | HV4 |  | LV4 |  | 9 |  | 16 | 7
D3 | HV3 | LV3 | 10 |  | 15 | 8 |  | D3 |  | HV3 |  | LV3 |  | 10 |  | 15 | 8
P4 | GND | GND | 11 |  | 14 | 9 |  | P4 |  | GND |  | GND |  | 11 |  | 14 | 9
D4 | HV | LV | 12 |  | 13 | 10 |  | D4 |  | HV |  | LV |  | 12 |  | 13 | 10
 | HV2 | LV2 | 3.3V |  | GND | 11 |  |  |  | HV2 |  | LV2 |  | 3.3V |  | GND | 11
 | HV1 | LV1 | 24 |  | 41 | 12 |  |  |  | HV1 |  | LV1 |  | 24 |  | 41 | 12
 |  |  | 25 |  | 40 | 13 |  |  |  |  |  |  |  | 25 |  | 40 | 13
 |  |  | 26 |  | 39 | 14 |  |  |  |  |  |  |  | 26 |  | 39 | 14
 |  |  | 27 |  | 38 | 15 | GND |  | GND | GND |  |  |  | 27 |  | 38 | 15
 |  |  | 28 |  | 37 |  | 3.3 |  | 3.3V | 3.3V |  |  |  | 28 |  | 37 |  | 3.3V
 |  |  | 29 |  | 36 |  | O0 |  | SCL | SCL |  |  |  | 29 |  | 36 |  | GND
 |  |  | 30 |  | 35 | TX |  |  | SDA | SDA |  |  |  | 30 |  | 35 | TX
 |  |  | 31 |  | 34 | RX |  |  |  |  |  |  |  | 31 |  | 34 | RX
 |  |  | 32 |  | 33 |  |  |  |  |  |  | SW | SW | 32 |  | 33

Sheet: Teensy board
 |  |  |  |  |  |  |  | USB PORT
 | 12V |  |  |  | 12V |  |  | USB PORT |  |  |  |  | GND
 |  |  |  |  |  |  |  | USB PORT |  | E
 | GND |  |  |  | GND |  |  | USB PORT |  |  | B |  | KICK
 |  |  |  |  |  |  |  | USB PORT |  |  |  |  |  |  |  |  |  |  |  |  | HV4 |  | LV4
 | 12V |  |  |  | 5V |  |  | USB PORT |  |  |  |  |  |  |  |  |  |  |  |  | HV3 |  | LV3
 |  |  |  |  |  |  |  | USB PORT |  |  |  |  |  |  |  |  |  |  |  |  | GND |  | GND
 | GND |  |  |  |  |  |  | USB PORT |  |  |  |  |  |  |  |  |  |  |  |  | HV |  | LV
 |  |  |  |  |  |  |  | USB PORT |  |  |  |  |  |  |  |  |  |  |  |  | HV2 |  | LV2
 | 12V |  |  |  |  |  |  | USB PORT |  |  |  |  |  |  |  |  |  |  |  |  | HV1 |  | LV1
 |  |  |  |  |  |  |  | USB PORT |  |  |  |  |  |  |  |  |  |  |  |  | HV4 |  | LV4
 | GND |  |  |  |  |  |  | USB PORT |  |  |  |  |  |  |  |  |  |  |  |  | HV3 |  | LV3
 |  |  |  |  |  | GND |  |  | 5V | Vin |  |  |  |  |  |  |  |  |  |  | GND |  | GND
 |  |  |  |  |  | 0 |  |  |  | GND |  |  |  |  |  |  |  |  |  |  | HV |  | LV
 |  |  |  |  |  | 1 |  |  |  | 3.3V |  |  |  |  |  |  |  |  |  |  | HV2 |  | LV2
 |  |  |  |  |  | 2 |  |  |  | 23 |  |  | 0 |  |  |  |  |  |  |  | HV1 |  | LV1
 | 1P | HV4 |  | LV4 |  | 3 |  |  |  | 22 |  |  | 1
 | 1D | HV3 |  | LV3 |  | 4 |  |  |  | 21 |  |  | 2
1P |  | GND |  | GND |  | 5 |  |  |  | 20 |  |  | 3
1D |  | HV |  | LV |  | 6 |  |  |  | 19 |  |  | 4
2P | 2P | HV2 |  | LV2 |  | 7 |  |  |  | 18 |  |  | 5
2D | 2D | HV1 |  | LV1 |  | 8 |  |  |  | 17 |  |  | 6
3P | 3P | HV4 |  | LV4 |  | 9 |  |  |  | 16 |  |  | 7
3D | 3D | HV3 |  | LV3 |  | 10 |  |  |  | 15 |  |  | 8
4P |  | GND |  | GND |  | 11 |  |  |  | 14 |  |  | 9
4D |  | HV |  | LV |  | 12 |  |  |  | 13 |  |  | 10 |  | 5V
 | 4P | HV2 |  | LV2 |  | 3.3V |  |  |  | GND |  |  | 11
 | 4D | HV1 |  | LV1 |  | 24 |  |  |  | 41 |  |  | 12 |  | GND
 |  |  |  |  |  | 25 |  |  |  | 40 |  |  | 13
 | 3.3V | 3.3V |  |  |  | 26 |  |  |  | 39 |  |  | 14 |  | 12V
 | GND | GND |  |  |  | 27 |  |  |  | 38 |  |  | 15
 | SCL | SCL |  |  |  | 28 |  |  |  | 37
 | SDA | SDA |  |  |  | 29 |  |  |  | 36
 |  |  |  |  |  | 30 |  |  |  | 35 |  |  | TX
 | 3.3V | 3.3V |  |  |  | 31 |  |  |  | 34 |  |  | RX
 | GND | GND |  |  |  | 32 |  |  |  | 33
 |  |  |  | SW | SW |  |  | SCM
 | 3.3V | 3.3V |  |  |  |  |  | 3.3V
 | GND | GND |  |  |  |  |  | GND
 |  |  |  |  |  |  |  |  |  |  |  |  |  |  |  |  | ak sa pouzije externy menic napatia s low gnd high vstupmi
 | 5V | 5V |  |  |  | GND |  |  | 5V | Vin |  | 5V | 5V |  |  |  | 5V |  |  | GND |  |  | 5V | Vin |  | 5V | 5V
 | GND | GND |  |  |  | 0 |  |  |  | GND |  | GND | GND |  |  |  | GND |  |  | 0 |  |  |  | GND |  | GND | GND
 |  |  |  |  |  | 1 |  |  |  | 3.3V |  |  |  |  |  |  |  |  |  | 1 |  |  |  | 3.3V
 |  |  |  |  |  | 2 |  |  |  | 23 |  |  | 0 |  |  |  |  |  |  | 2 |  |  |  | 23 |  |  | 0
 | 1P | HV4 |  | LV4 |  | 3 |  |  |  | 22 |  |  | 1 |  | 1P | HV4 |  | LV4 |  | 3 |  |  |  | 22 |  |  | 1
 | 1D | HV3 |  | LV3 |  | 4 |  |  |  | 21 |  |  | 2 |  | 1D | HV3 |  | LV3 |  | 4 |  |  |  | 21 |  |  | 2
1P |  | GND |  | GND |  | 5 |  |  |  | 20 |  |  | 3 | 1P |  | GND |  | GND |  | 5 |  |  |  | 20 |  |  | 3
1D |  | HV |  | LV |  | 6 |  |  |  | 19 |  |  | 4 | 1D |  | HV |  | LV |  | 6 |  |  |  | 19 |  |  | 4
2P | 2P | HV2 |  | LV2 |  | 7 |  |  |  | 18 |  |  | 5 | 2P | 2P | HV2 |  | LV2 |  | 7 |  |  |  | 18 |  |  | 5
2D | 2D | HV1 |  | LV1 |  | 8 |  |  |  | 17 |  |  | 6 | 2D | 2D | HV1 |  | LV1 |  | 8 |  |  |  | 17 |  |  | 6
3P | 3P | HV4 |  | LV4 |  | 9 |  |  |  | 16 |  |  | 7 | 3P | 3P | HV4 |  | LV4 |  | 9 |  |  |  | 16 |  |  | 7
3D | 3D | HV3 |  | LV3 |  | 10 |  |  |  | 15 |  |  | 8 | 3D | 3D | HV3 |  | LV3 |  | 10 |  |  |  | 15 |  |  | 8
4P |  | GND |  | GND |  | 11 |  |  |  | 14 |  |  | 9 | 4P |  | GND |  | GND |  | 11 |  |  |  | 14 |  |  | 9
4D |  | HV |  | LV |  | 12 |  |  |  | 13 |  |  | 10 | 4D |  | HV |  | LV |  | 12 |  |  |  | 13 |  |  | 10
 | 4P | HV2 |  | LV2 |  | 3.3V |  |  |  | GND |  |  | 11 |  | 4P | HV2 |  | LV2 |  | 3.3V |  |  |  | GND |  |  | 11
 | 4D | HV1 |  | LV1 |  | 24 |  |  |  | 41 |  |  | 12 |  | 4D | HV1 |  | LV1 |  | 24 |  |  |  | 41 |  |  | 12
 |  |  |  |  |  | 25 |  |  |  | 40 |  |  | 13 |  |  |  |  |  |  | 25 |  |  |  | 40 |  |  | 13
 | 3.3V | 3.3V |  |  |  | 26 |  |  |  | 39 |  |  | 14 |  | 3.3V | 3.3V |  |  |  | 26 |  |  |  | 39 |  |  | 14
 | GND | GND |  |  |  | 27 |  |  |  | 38 |  |  | 15 |  | GND | GND |  |  |  | 27 |  |  |  | 38 |  |  | 15
 | SCL | SCL |  |  |  | 28 |  |  |  | 37 |  |  |  |  | SCL | SCL |  |  |  | 28 |  |  |  | 37
 | SDA | SDA |  |  |  | 29 |  |  |  | 36 |  |  |  |  | SDA | SDA |  |  |  | 29 |  |  |  | 36
 |  |  |  |  |  | 30 |  |  |  | 35 |  |  | TX |  |  |  |  |  |  | 30 |  |  |  | 35 |  |  | TX
 | 3.3V | 3.3V |  |  |  | 31 |  |  |  | 34 |  |  | RX |  | 3.3V | 3.3V |  |  |  | 31 |  |  |  | 34 |  |  | RX
 | GND | GND |  |  |  | 32 |  |  |  | 33 |  |  |  |  | GND | GND |  | SW | SW | 32 |  |  |  | 33 | SCM
 |  |  |  | SW | SW
 | 3.3V | 3.3V
 | GND | GND |  |  |  |  |  |  |  |  |  |  |  |  |  |  |  |  |  |  |  |  |  |  |  |  | 5V
 |  |  |  |  |  |  |  |  |  |  |  |  |  |  | 12V |  |  |  |  |  |  | 5V | GND
 |  |  |  |  |  |  |  |  |  |  |  |  |  |  |  |  |  |  |  |  |  | 5V | GND |  |  |  | GND
 |  |  |  |  |  |  |  |  |  |  |  |  |  |  | GND |  |  |  |  |  |  | 5V | GND
 |  |  |  |  |  |  |  |  |  |  |  |  |  |  |  |  |  |  |  |  |  | 5V | GND |  |  |  | 12V
 |  |  |  |  |  |  |  |  |  |  |  |  |  |  | 12V |  |  |  |  |  |  | 5V | GND
 |  |  |  |  |  |  |  |  |  |  |  |  | O0 |  | GND |  |  |  |  |  |  |  |  |  |  |  | K+
 |  |  |  |  |  |  |  |  |  |  |  |  | O1
 |  |  |  |  |  |  | GND |  |  |  |  |  | RX |  | 12V |  |  |  |  |  |  |  |  |  |  |  | K-
 |  |  | GND |  |  |  | 3.3V |  |  |  |  |  | TX
 |  |  | BAT |  |  |  | LGV |  |  |  |  |  | D+ |  | GND |  |  |  |  |  |  | BAS | COL
 |  |  |  |  |  |  | VIN |  |  |  |  |  | D- |  |  |  |  |  |  |  |  | EM
 | 5V | 5V |  |  |  | GND |  |  | 5V | Vin |  | 5V | 5V
 | GND | GND |  |  |  | 0 |  |  |  | GND |  | GND | GND
 |  |  |  |  |  | 1 |  |  |  | 3.3V
 |  |  |  |  |  | 2 |  |  |  | 23 |  |  | 0
 | 1P | HV4 |  | LV4 |  | 3 |  |  |  | 22 |  |  | 1
 | 1D | HV3 |  | LV3 |  | 4 |  |  |  | 21 |  |  | 2
1P |  | GND |  | GND |  | 5 |  |  |  | 20 |  |  | 3
1D |  | HV |  | LV |  | 6 |  |  |  | 19 |  |  | 4
2P | 2P | HV2 |  | LV2 |  | 7 |  |  |  | 18 |  |  | 5
2D | 2D | HV1 |  | LV1 |  | 8 |  |  |  | 17 |  |  | 6
3P | 3P | HV4 |  | LV4 |  | 9 |  |  |  | 16 |  |  | 7
3D | 3D | HV3 |  | LV3 |  | 10 |  |  |  | 15 |  |  | 8
4P |  | GND |  | GND |  | 11 |  |  |  | 14 |  |  | 9
4D |  | HV |  | LV |  | 12 |  |  |  | 13 |  |  | 10
 | 4P | HV2 |  | LV2 |  | 3.3V |  |  |  | GND |  |  | 11
 | 4D | HV1 |  | LV1 |  | 24 |  |  |  | 41 |  |  | 12
 |  |  |  |  |  | 25 |  |  |  | 40 |  |  | 13
 | 3.3V | 3.3V |  |  |  | 26 |  |  |  | 39 |  |  | 14
 | GND | GND |  |  |  | 27 |  |  |  | 38 |  |  | 15
 | SCL | SCL |  |  |  | 28 |  |  |  | 37
 | SDA | SDA |  |  |  | 29 |  |  |  | 36
 |  |  |  |  |  | 30 |  |  |  | 35 |  |  | TX
 | 3.3V | 3.3V |  |  |  | 31 |  |  |  | 34 |  |  | RX
 | GND | GND |  |  |  | 32 |  |  |  | 33
 |  |  |  | SW | SW |  |  | SCM
 | 3.3V | 3.3V |  |  |  |  |  | 3.3V
 | GND | GND |  |  |  |  |  | GND
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

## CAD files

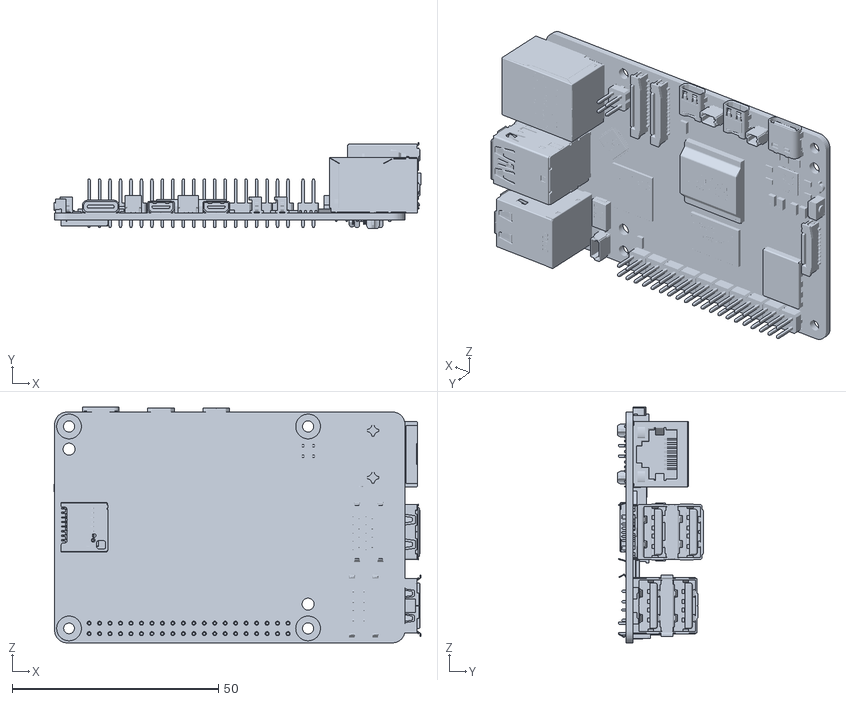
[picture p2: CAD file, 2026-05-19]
hardware/3d_models/raspberry_pi_5.stl
89.0 x 20.8 x 57.2

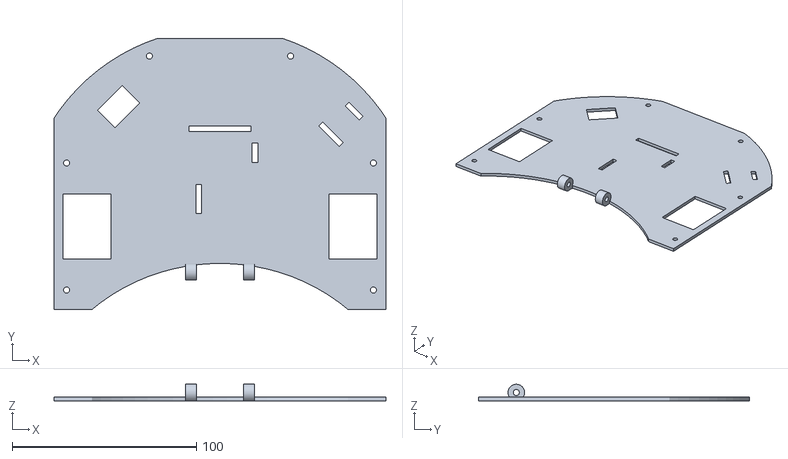
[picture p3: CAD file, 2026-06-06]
hardware/3d_models/stl/upper_part.stl
180.0 x 147.0 x 9.00

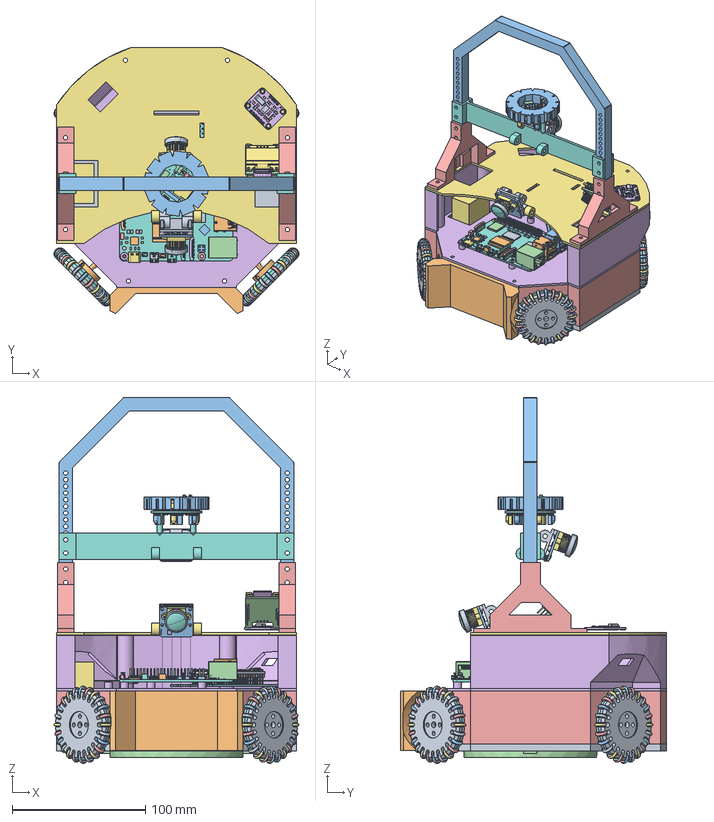
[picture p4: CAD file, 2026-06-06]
hardware/3d_render/robot_updated.FCStd
183.6 x 199.3 x 274.3 mm
Bottom Part Solid
Ball Zone Solid
Handle Solid
Line Sensoe Shield Solid
Handle Bracket Solid
Middle Part Solid
Upper Part Solid
Uppest Part Solid
Camera Bracket Solid x 2
Motor 001 x 4
6067963024.step x 2
6067963424.step x 2
6067964544.step x 2
User_Library-CAPC_0402_CAPC_0402_Lead_1.step x 2
User_Library-CAPC_0402_CAPC_0402_Lead_1.step001 x 2
User_Library-CAPC_0402_CAPC_0402_Body_1.step x 2
6067964544.step001 x 2
6067963024.step001 x 2
74479787147.step x 2
L__X2__00F6__X0__tende.step x 2
L__X2__00F6__X0__tende.step001 x 2
6067963024.step002 x 2
6067964464.step x 2
6067964464.step001 x 2
6067963424.step001 x 2
User_Library-CAPC_0402_CAPC_0402_Lead_1-0.step x 2
User_Library-CAPC_0402_CAPC_0402_Lead_1-0.step001 x 2
User_Library-CAPC_0402_CAPC_0402_Body_1-1.step x 2
User_Library-CAPC_0402_CAPC_0402_Lead_1-2.step x 2
User_Library-CAPC_0402_CAPC_0402_Lead_1-2.step001 x 2
User_Library-CAPC_0402_CAPC_0402_Body_1-3.step x 2
User_Library-CAPC_0402_CAPC_0402_Lead_1-2.step002 x 2
User_Library-CAPC_0402_CAPC_0402_Lead_1-2.step003 x 2
User_Library-CAPC_0402_CAPC_0402_Body_1-3.step001 x 2
User_Library-CAPC_0402_CAPC_0402_Lead_1.step002 x 2
User_Library-CAPC_0402_CAPC_0402_Lead_1.step003 x 2
User_Library-CAPC_0402_CAPC_0402_Body_1.step001 x 2
User_Library-CAPC_0402_CAPC_0402_Lead_1-2.step004 x 2
User_Library-CAPC_0402_CAPC_0402_Lead_1-2.step005 x 2
User_Library-CAPC_0402_CAPC_0402_Body_1-3.step002 x 2
User_Library-CAPC_0402_CAPC_0402_Lead_1-2.step006 x 2
User_Library-CAPC_0402_CAPC_0402_Lead_1-2.step007 x 2
User_Library-CAPC_0402_CAPC_0402_Body_1-3.step003 x 2
User_Library-CAPC_0402_CAPC_0402_Lead_1-2.step008 x 2
User_Library-CAPC_0402_CAPC_0402_Lead_1-2.step009 x 2
User_Library-CAPC_0402_CAPC_0402_Body_1-3.step004 x 2
User_Library-CAPC_0402_CAPC_0402_Lead_1.step004 x 2
User_Library-CAPC_0402_CAPC_0402_Lead_1.step005 x 2
User_Library-CAPC_0402_CAPC_0402_Body_1.step002 x 2
User_Library-CAPC_0402_CAPC_0402_Lead_1.step006 x 2
User_Library-CAPC_0402_CAPC_0402_Lead_1.step007 x 2
User_Library-CAPC_0402_CAPC_0402_Body_1.step003 x 2
User_Library-CAPC_0402_CAPC_0402_Lead_1.step008 x 2
User_Library-CAPC_0402_CAPC_0402_Lead_1.step009 x 2
User_Library-CAPC_0402_CAPC_0402_Body_1.step004 x 2
User_Library-CAPC_0402_CAPC_0402_Lead_1.step010 x 2
User_Library-CAPC_0402_CAPC_0402_Lead_1.step011 x 2
User_Library-CAPC_0402_CAPC_0402_Body_1.step005 x 2
User_Library-CAPC_0402_CAPC_0402_Lead_1-4.step x 2
User_Library-CAPC_0402_CAPC_0402_Lead_1-4.step001 x 2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

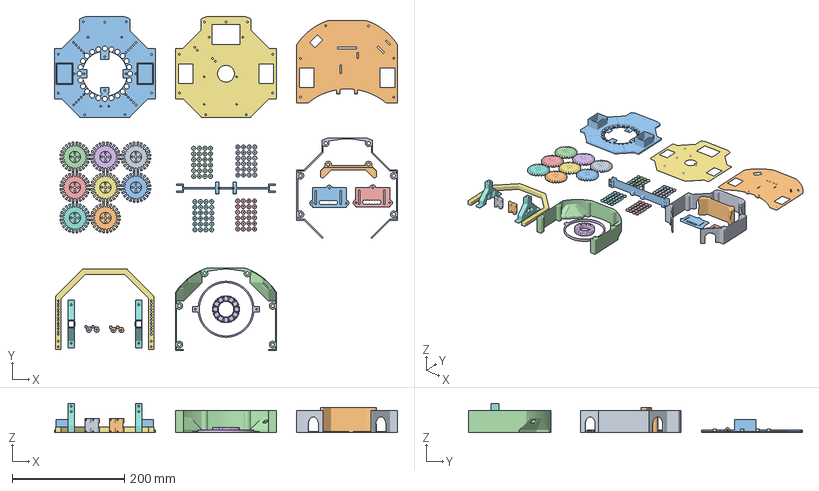
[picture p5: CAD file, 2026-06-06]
hardware/bambulab_a1_mini.3mf
612.0 x 595.5 x 52.5 mm
omniwheel-small_wheels.stl x 4
ball_zone.stl
bottom_part.stl
line_sensor_shield.stl
middle_part.stl
bottom_wall.stl
upper_part.stl
driver_bracket.stl x 2
middle_wall.stl
IRFinderCover v3.stl
handle.stl
handle_bracket.stl
camera_bracket.stl x 2
uppest_part.stl
omniwheel_base.stl x 8

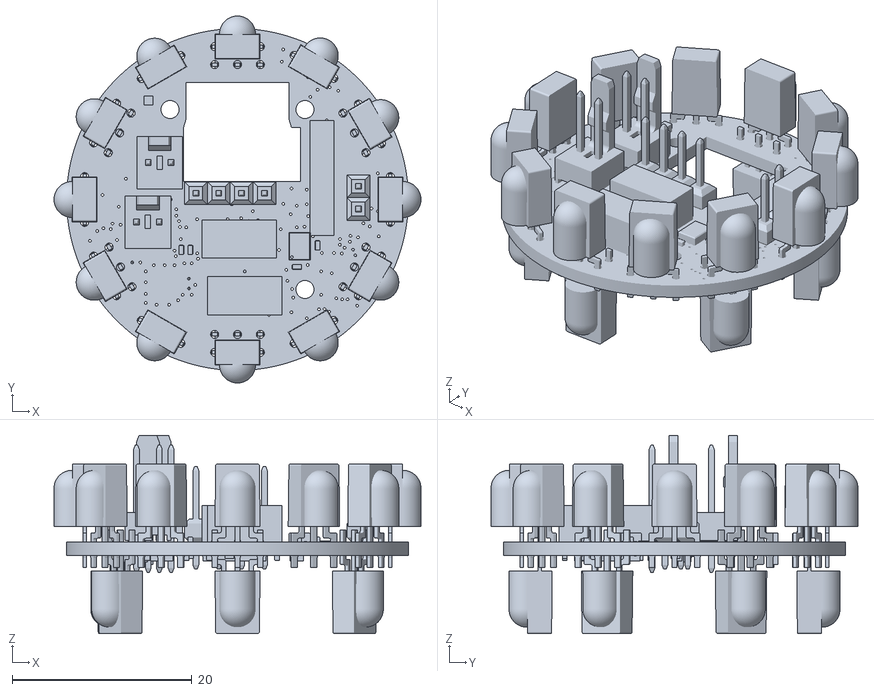
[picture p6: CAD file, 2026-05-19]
hardware/3d_models/mrm-ir-finder3.stl
40.8 x 40.8 x 22.0

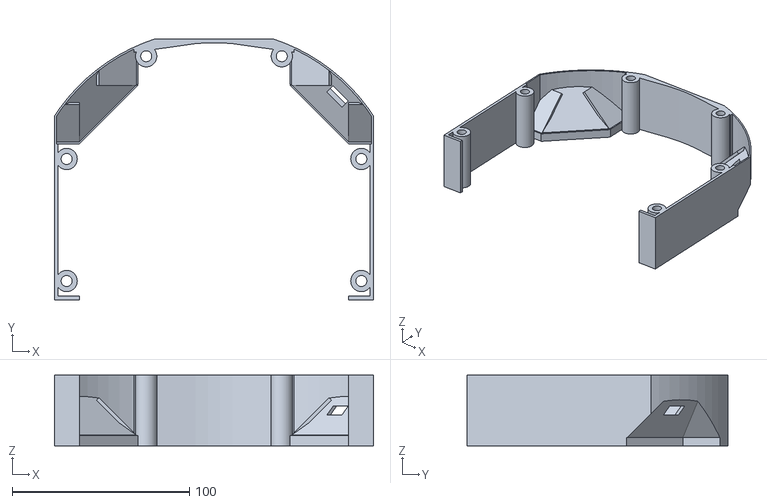
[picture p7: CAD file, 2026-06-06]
hardware/3d_models/stl/middle_wall.stl
180.0 x 147.0 x 39.8

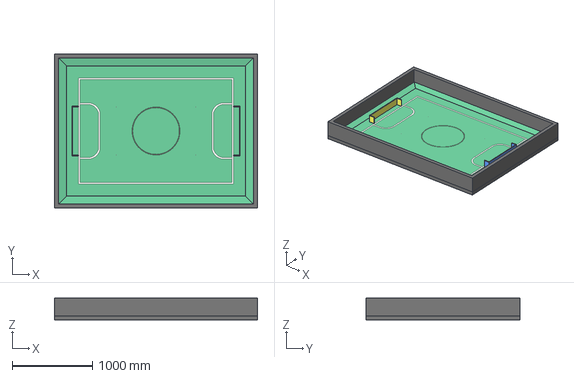
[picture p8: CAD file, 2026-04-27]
hardware/3d_render/field.step
2530.0 x 1920.0 x 270.0 mm

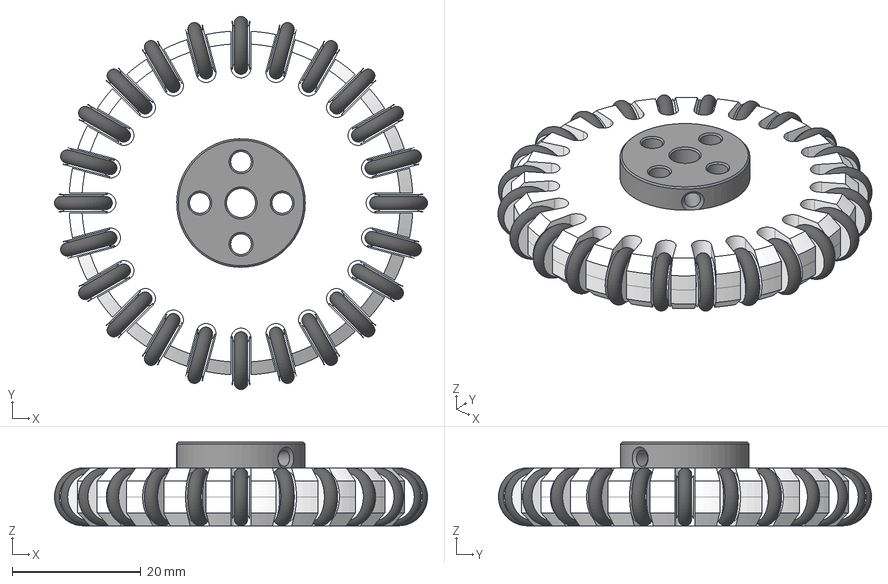
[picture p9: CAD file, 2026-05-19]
hardware/3d_models/omniwheel.step
58.0 x 58.0 x 13.0 mm
SmallWheelBaseBody x 24
SmallWheelRubberBody x 24
AlumuniumHubBody

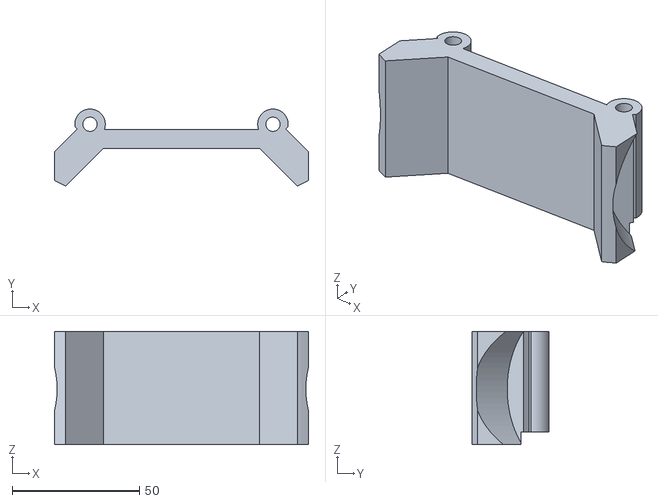
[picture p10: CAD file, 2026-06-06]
hardware/3d_models/stl/ball_zone.stl
100.0 x 30.3 x 44.6

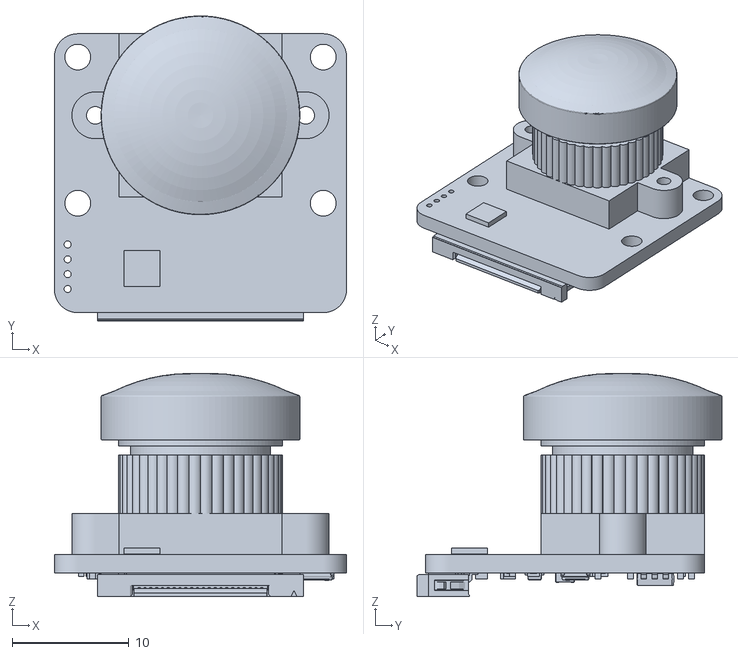
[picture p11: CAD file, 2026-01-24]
hardware/3d_models/B0310.stl
25.0 x 26.1 x 19.1

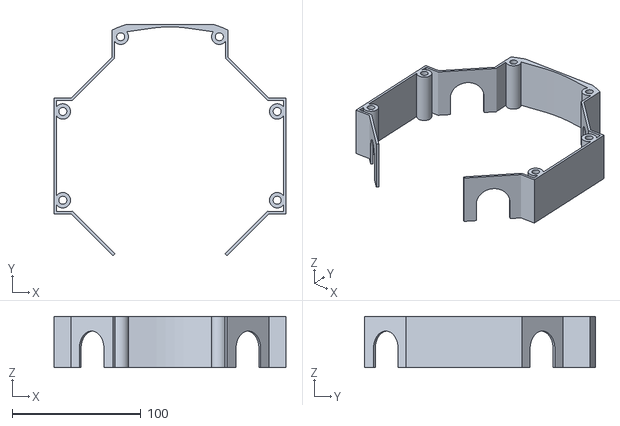
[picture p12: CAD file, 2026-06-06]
hardware/3d_models/stl/bottom_wall.stl
180.0 x 179.4 x 39.8

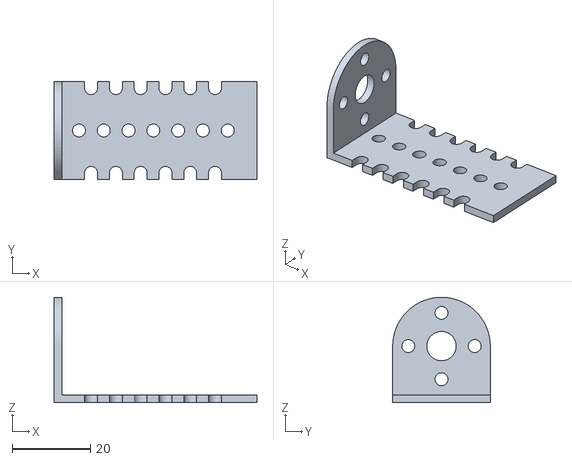
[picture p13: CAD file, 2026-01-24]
hardware/3d_models/motor_bracket.stl
52.0 x 25.0 x 27.0

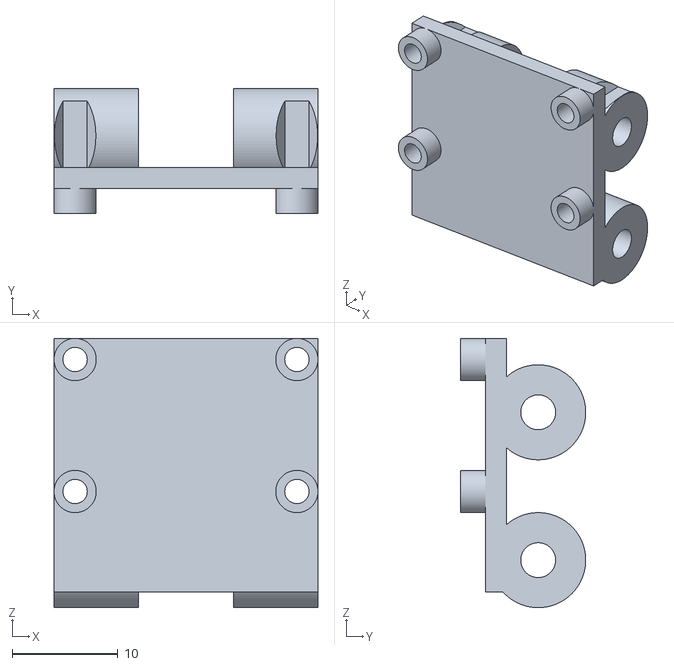
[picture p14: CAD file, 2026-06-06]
hardware/3d_models/stl/camera_bracket.stl
25.0 x 11.9 x 25.5

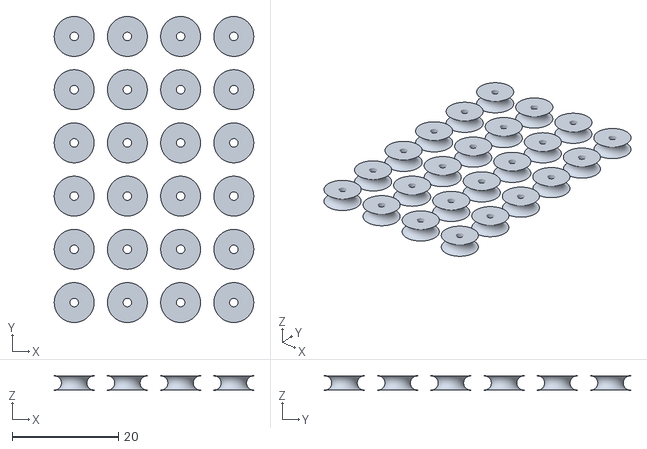
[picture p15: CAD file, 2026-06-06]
hardware/3d_models/stl/omniwheel_small_wheels.stl
37.5 x 57.5 x 2.70

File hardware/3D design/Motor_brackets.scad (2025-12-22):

wheel_d = 55;
wheel_h = 12.5;
wheel_offset = 90;
robot_d = 215;
robot_h = 220;

// Motor bracket
width = 25;
thickness = 2;
height = 27;
lenght = 52;
num_holes = 7;
hole_set = 6.35;

ballDiameter = 43;
module motor_bracket_holes() {
    for (A = [0:90:359]){
        rotate([0,0,A + 45])
        translate([wheel_offset - 5,0,0])
        for (B = [0:1:num_holes-1]) {
            rotate([0,0,180])
            translate([0,0,-14.5])
            translate([B*hole_set + 6.4,0,0])
            cylinder(d = 3.3, h = 100,center=true);
        }
    }
}
module motor_bracket() {
    rotate([0,0,180])translate([0,0,-14.5])
    difference() {
        union() {
            translate([lenght/2,0,thickness/2])
                cube([lenght,width,thickness],center=true);
            translate([thickness/2,0,height/2])
                cube([thickness,width,height],center=true);
        }
         for (B = [-1, 1]) {
            rotate([0,90,0])translate([B*8.5 - 14.5,0,0])
                cylinder(d = 3.3, h = 100,center=true);
             rotate([90,0,90])translate([B*8.5,14.5,0])
                cylinder(d = 3.3, h = 100,center=true);
        }
        translate([0,0,14.5])rotate([0,90,0])
            cylinder(d = 7.5,h = 100, center=true);
        difference() {
            translate([0,0,27])cube([20,30,25],center=true);
            translate([0,0,14.5])rotate([0,90,0])
                cylinder(d = 25,h = 100, center=true);
        }
        
        
        for (B = [0:1:num_holes-1]) {
            translate([B*hole_set + 6.4,0,0])
                cylinder(d = 3.3, h = 100,center=true);
        }
        for (B = [0:1:num_holes-2]) for (C = [1, -1]){
            translate([B*hole_set + 9.5,C*21.7/2,0]) {
                cylinder(d = 3.3, h = 100,center=true);
                translate([0,C*2,0])cube([3.3,4,100], center=true);
            }
        }
        
    }
}
module motors() {
    translate([0,0,wheel_d/2]) for (A = [0:90:359]){
        rotate([A,90,45]) translate([0,0,wheel_offset-3]) {
            difference() {
                union() {
                    translate([0,0,-(motor_L + 30.8)/2-2.5-10/2])
                      cylinder(h = (motor_L + 30.8), d = 24.4, center=true);
                    translate([0,0,-2.5/2-10/2])
                      cylinder(h = 2.5, d = 7, center=true);
                    translate([0,0,-10/2])
                      cylinder(h = 10, d = 4);
                }
                for(B = [-1, 1]) {
                    translate([0,B*8.5,-10])cylinder(d = 3.3, h = 10);
                }
            }
        }
    }
}


module motor_brackets_all() {
    translate([0,0,wheel_d/2])
    for (A = [0:90:359]){
        rotate([0,0,A + 45])
            translate([wheel_offset - 5,0,0])
                motor_bracket();
    }
}

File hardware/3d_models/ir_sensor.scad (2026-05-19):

$fn = 90;

module ir_sensor_bracket_holes(
    hole_d = 3.3,
    hole_height = 200,
    hole_offset = 8,
    angles = [0:90:359]
) {
    for (angle = angles) {
        rotate([0, 0, angle])
            translate([hole_offset, 0, 0])
                cylinder(d = hole_d, h = hole_height, center = true);
    }
}

module ir_sensor_holes(
    hole_d = 2,
    hole_height = 200,
    hole_positions = [[-7.5, 10], [7.5, 10], [7.5, -10]]
) {
    for (pos = hole_positions) {
        translate([pos[0], pos[1], 0])
            cylinder(d = hole_d, h = hole_height, center = true);
    }
}

module ir_sensor_bracket(
    base_d = 42,
    base_h = 2,
    base_z_offset = -11,
    holder_d = 8,
    holder_h = 10,
    holder_offset = 15.5,
    holder_z_offset = -6,
    holder_clear_d = 7,
    holder_clear_h = 100,
    holder_slot_size = [3, 10, 100],
    holder_slot_offset = [0, 5, 0],
    cable_hole_d = 10,
    cable_hole_h = 100,
    bracket_hole_d = 3.3,
    bracket_hole_h = 200,
    sensor_hole_d = 2,
    sensor_hole_h = 200
) {
    difference() {
        union() {
            translate([0, 0, base_z_offset])
                cylinder(d = base_d, h = base_h, center = true);
            for (angle = [0:60:359]) {
                rotate([0, 0, angle])
                    translate([0, holder_offset, holder_z_offset])
                        difference() {
                            cylinder(h = holder_h, d = holder_d, center = true);
                            cylinder(h = holder_clear_h, d = holder_clear_d, center = true);
                            translate(holder_slot_offset)
                                cube(holder_slot_size, center = true);
                        }
            }
        }
        cylinder(d = cable_hole_d, h = cable_hole_h, center = true);
        ir_sensor_bracket_holes(hole_d = bracket_hole_d, hole_height = bracket_hole_h);
        ir_sensor_holes(hole_d = sensor_hole_d, hole_height = sensor_hole_h);
    }
}

module ir_sensor(model_path = "mrm-ir-finder3.stl", model_offset = [-21, -21, 0]) {
    translate(model_offset)
        import(model_path);
}

ir_sensor_bracket();

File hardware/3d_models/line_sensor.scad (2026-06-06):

$fn = 90;

use <robot_shared.scad>;

module led(color = "yellow") {
    color(color) difference() {
        union() {
            sphere(d = 3);
            cylinder(d = 3, h = 3);
            translate([0,0,2.5])cylinder(d = 4, h = 1);
        }
        translate([2.5,0,0])cube([2,100,100], center=true);
    }
    color("grey") for(A = [1, -1])
        translate([A,0,3])cylinder(d = 0.5, h = 5);
}

module line_sensor() {
    difference() {
        union() {
            color("darkgreen")cylinder(d = 100, h = 2);
            for(A = [0:15:360]) {
                rotate([0,0,A])translate([-45,0,-5]) {
                     if (A % 10 == 0)
                         led("black");
                     else
                         led("white");
                }
            }
        }
        translate([0,0,4])cylinder(d = 110, h = 20);
    }
}
line_sensor();

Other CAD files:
hardware/3d_models/stl/omniwheel_base.stl
hardware/3d_models/stl/uppest_part.stl
hardware/3d_models/stl/middle_part.stl
hardware/3d_models/stl/line_sensor_shield.stl
hardware/3d_models/line_sensor_shield.scad
hardware/3d_models/ball_zone.scad
hardware/3d_models/bottom_part.scad
hardware/3d_models/bottom_wall.scad
hardware/3d_models/camera_bracket.scad
hardware/3d_models/camera_bracket_holder.scad
hardware/3d_models/handle.scad
hardware/3d_models/handle_bracket.scad
hardware/3d_models/kicker.scad
hardware/3d_models/level_shifter.scad
hardware/3d_models/middle_part.scad
hardware/3d_models/middle_wall.scad
hardware/3d_models/motor_bracket.scad
hardware/3d_models/motor_driver_bracket.scad
hardware/3d_models/omniwheel.FCStd
hardware/3d_models/raspberry_pi.scad
hardware/3d_models/robot.scad
hardware/3d_models/robot_shared.scad
hardware/3d_models/stl/bottom_part.stl
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

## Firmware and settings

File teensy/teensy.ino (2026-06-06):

#include <i2c_driver.h>
#include "imx_rt1060/imx_rt1060_i2c_driver.h"
#include <math.h>
#include <string.h>


// ================================================
// =                Definitions                   =
// ================================================


struct Button {
  int pin;
  int lastState;
  int state;
  unsigned long lastDebounceTime;
};

enum DebugLevel {
  DEBUG_INFO,
  DEBUG_WARN,
  DEBUG_ERROR
};


#define TARGET_UPS 245
#define INTERVAL_US (1000000 / TARGET_UPS)


// ========== Control Switches ==========
#define MAIN_SWITCH_PIN 31
#define MAIN_SWITCH_LED_PIN 28
#define MODULE_SWITCH_PIN 32
#define MODULE_SWITCH_LED_PIN 29
#define MODULE_PIN 33
#define MODULE_LED_PIN 30

bool module_value = true;
bool is_running = false;

Button main_switch = {MAIN_SWITCH_PIN, HIGH, HIGH, 0};
bool main_switch_enabled = false;
Button module_switch = {MODULE_SWITCH_PIN, HIGH, HIGH, 0};
bool bt_module_enabled = true;


// ========== Serial Communication ==========
#define RASPBERRY_SERIAL Serial8
#define RASPBERRY_SERIAL_SPEED 230400

#define RASPBERRY_SERIAL_BUFFER_SIZE 128
char message_buffer[RASPBERRY_SERIAL_BUFFER_SIZE];

#define SENSOR_DATA_MESSAGE_TYPE 0x01
#define SENSOR_DATA_MESSAGE_LENGTH 14 + LINE_SENSOR_COUNT * 3
#define RUNNING_STATE_MESSAGE_TYPE 0x02
#define RUNNING_STATE_MESSAGE_LENGTH 4
#define SET_MOTORS_MESSAGE_TYPE 0xFF
#define SET_MOTORS_MESSAGE_LENGTH 8


#define DEBUG_PRINTS_ENABLED false
#define DEBUG_LOGS_ENABLED false
#define DEBUG_PROFILING_ENABLED true
#define DEBUG_PROFILING_PRINT_INTERVAL_S 1
#define DEBUG_SERIAL Serial


#if DEBUG_PRINTS_ENABLED
  template<typename T>
  inline void DEBUG_PRINT(const T& msg) {
    DEBUG_SERIAL.print(msg);
  }

  template<typename T>
  inline void DEBUG_PRINTLN(const T& msg) {
    DEBUG_SERIAL.println(msg);
  }

  inline void DEBUG_PRINTLN() {
    DEBUG_SERIAL.println();
  }
#else
  template<typename T> inline void DEBUG_PRINT(const T&) {}
  template<typename T> inline void DEBUG_PRINTLN(const T&) {}
  inline void DEBUG_PRINTLN() {}
#endif

#if DEBUG_LOGS_ENABLED
  template<typename T>
  inline void DEBUG_LOG(DebugLevel level, const T& msg) {
    switch (level) {
      case DEBUG_INFO:  DEBUG_SERIAL.print("[INFO]  "); break;
      case DEBUG_WARN:  DEBUG_SERIAL.print("[WARN]  "); break;
      case DEBUG_ERROR: DEBUG_SERIAL.print("[ERROR] "); break;
    }
    DEBUG_SERIAL.println(msg);
  }
#else
  template<typename T> inline void DEBUG_LOG(DebugLevel, const T&) {}
#endif

#if DEBUG_PROFILING_ENABLED
  struct TimingStat {
    unsigned long duration_sum = 0;
    unsigned long duration_min = UINT32_MAX;
    unsigned long duration_max = 0;
    
    unsigned long interval_sum = 0;
    unsigned long interval_min = UINT32_MAX;
    unsigned long interval_max = 0;
    
    unsigned long call_count = 0;
    unsigned long last_call_time = 0;
  };

  const int MAX_PROFILING_POINTS = 20;
  struct ProfilingData {
    const char* names[MAX_PROFILING_POINTS];
    TimingStat stats[MAX_PROFILING_POINTS];
    int count = 0;
  };
  
  ProfilingData profiling_data;
  static unsigned long last_timing_print = 0;

  int get_or_create_profiling_point(const char* name) {
    for (int i = 0; i < profiling_data.count; i++) {
      if (profiling_data.names[i] == name) {
        return i;
      }
    }
    if (profiling_data.count < MAX_PROFILING_POINTS) {
      profiling_data.names[profiling_data.count] = name;
      return profiling_data.count++;
    }
    return -1;
  }

  inline void DEBUG_PROFILING_START(unsigned long& checkpoint) {
    checkpoint = micros();
  }

  inline void DEBUG_PROFILING_RECORD(unsigned long checkpoint, const char* label) {
    unsigned long elapsed = micros() - checkpoint;
    int idx = get_or_create_profiling_point(label);
    if (idx >= 0) {
      TimingStat& stat = profiling_data.stats[idx];
      stat.duration_sum += elapsed;
      if (elapsed < stat.duration_min) stat.duration_min = elapsed;
      if (elapsed > stat.duration_max) stat.duration_max = elapsed;
      
      unsigned long now = micros();
      if (stat.last_call_time > 0) {
        unsigned long interval = now - stat.last_call_time;
        stat.interval_sum += interval;
        if (interval < stat.interval_min) stat.interval_min = interval;
        if (interval > stat.interval_max) stat.interval_max = interval;
      }
      stat.last_call_time = now;
      stat.call_count++;
    }
  }

  void print_profiling_value(unsigned long value, int width, bool is_null) {
    if (is_null) {
      DEBUG_SERIAL.print("");
      for (int j = 0; j < width; j++) DEBUG_SERIAL.print(" ");
    } else {
      String val_str = String(value);
      DEBUG_SERIAL.print(val_str);
      for (int j = val_str.length(); j < width; j++) DEBUG_SERIAL.print(" ");
    }
  }

  void DEBUG_PROFILING_PRINT_IF_READY() {
    unsigned long current_time = millis();
    if (current_time - last_timing_print >= DEBUG_PROFILING_PRINT_INTERVAL_S * 1000) {
      last_timing_print = current_time;
      
      DEBUG_SERIAL.println();
      DEBUG_SERIAL.println("┌──────────────────────────┬────────────────────────────────┬────────────────────────────────┬─────────┐");
      DEBUG_SERIAL.println("│ Function                 │ Duration (µs)                  │ Interval (µs)                  │ Calls/s │");
      DEBUG_SERIAL.println("│                          │ Avg      Min      Max          │ Avg      Min      Max          │         │");
      DEBUG_SERIAL.println("├──────────────────────────┼────────────────────────────────┼────────────────────────────────┼─────────┤");
      
      for (int i = 0; i < profiling_data.count; i++) {
        TimingStat& stat = profiling_data.stats[i];
        if (stat.call_count > 0) {
          bool has_duration_data = (stat.duration_min != UINT32_MAX);
          bool has_interval_data = (stat.call_count > 1);
          
          DEBUG_SERIAL.print("│ ");
          DEBUG_SERIAL.print(profiling_data.names[i]);
          int name_len = strlen(profiling_data.names[i]);
          for (int j = name_len; j < 24; j++) DEBUG_SERIAL.print(" ");
          
          DEBUG_SERIAL.print(" │ ");
          if (has_duration_data) {
            unsigned long duration_avg = stat.duration_sum / stat.call_count;
            print_profiling_value(duration_avg, 8, false);
            DEBUG_SERIAL.print(" ");
            print_profiling_value(stat.duration_min, 8, false);
            DEBUG_SERIAL.print(" ");
            print_profiling_value(stat.duration_max, 9, false);
          } else {
            print_profiling_value(0, 8, true);
            DEBUG_SERIAL.print(" ");
            print_profiling_value(0, 8, true);
            DEBUG_SERIAL.print(" ");
            print_profiling_value(0, 9, true);
          }
          
          DEBUG_SERIAL.print("    │ ");
          if (has_interval_data) {
            unsigned long interval_avg = stat.interval_sum / (stat.call_count - 1);
            print_profiling_value(interval_avg, 8, false);
            DEBUG_SERIAL.print(" ");
            print_profiling_value(stat.interval_min, 8, false);
            DEBUG_SERIAL.print(" ");
            print_profiling_value(stat.interval_max, 9, false);
          } else {
            print_profiling_value(0, 8, true);
            DEBUG_SERIAL.print(" ");
            print_profiling_value(0, 8, true);
            DEBUG_SERIAL.print(" ");
            print_profiling_value(0, 9, true);
          }
          
          DEBUG_SERIAL.print("    │ ");
          if (has_interval_data) {
            unsigned long interval_avg = stat.interval_sum / (stat.call_count - 1);
            unsigned long calls_per_sec = (interval_avg > 0) ? (1000000 / interval_avg) : 0;
            String cps_str = String(calls_per_sec);
            DEBUG_SERIAL.print(cps_str);
            for (int j = cps_str.length(); j < 6; j++) DEBUG_SERIAL.print(" ");
          } else {
            DEBUG_SERIAL.print("      ");
          }
          
          DEBUG_SERIAL.println("  │");
        }
      }
      
      DEBUG_SERIAL.println("└──────────────────────────┴────────────────────────────────┴────────────────────────────────┴─────────┘");
      
      for (int i = 0; i < profiling_data.count; i++) {
        profiling_data.stats[i] = {0, UINT32_MAX, 0, 0, UINT32_MAX, 0, 0, 0};
      }
    }
  }
#else
  struct TimingStat {};
  inline void DEBUG_PROFILING_START(unsigned long&) {}
  inline void DEBUG_PROFILING_RECORD(unsigned long, const char*) {}
  void DEBUG_PROFILING_PRINT_IF_READY() {}
#endif


// ========== Motors Configuration ==========
#define MOTOR_COUNT 4
#define PWM_INDEX 0
#define DIR_INDEX 1
#define MOTOR_STOPPED 0
#define KICKER_OUT 1
#define KICKER_IN 0

// [PWM_PIN, DIR_PIN]
const int motor_pin_config[MOTOR_COUNT][2] = {
  { 6, 5 },
  { 8, 7 },
  { 10, 9 },
  { 12, 11 },
};
const int kicker_pin = 4;

struct MotorsData {
  int16_t motor_speed[MOTOR_COUNT];
  int8_t kicker_position;
};

MotorsData motors_data = { { 0, 0, 0, 0 }, KICKER_IN };


// ========== BNO055 Compass Sensor ==========
#define BNO055_I2C_ADDRESS 0x28
#define BNO055_CHIP_ID 0xA0
#define BNO055_CHIP_ID_ADDR 0x00
#define BNO055_EULER_H_LSB_ADDR 0x1A
#define BNO055_OPR_MODE_ADDR 0x3D
#define BNO055_PWR_MODE_ADDR 0x3E
#define BNO055_SYS_TRIGGER_ADDR 0x3F
#define BNO055_PAGE_ID_ADDR 0x07
#define BNO055_OPR_MODE_CONFIG 0x00
#define BNO055_OPR_MODE_NDOF 0x08
#define BNO055_POWER_MODE_NORMAL 0x00

I2CMaster& i2c_master = Master;
bool bno_initialized = false;
unsigned long bno_next_retry_at_ms = 0;
unsigned long i2c_req_checkpoint;

struct CompassData {
  float heading;
  float pitch;
  float roll;
};
CompassData compass_data = { 0.0, 0.0, 0.0 };


// ========== MRM-IR-Finder3 Sensor ==========
#define IR_I2C_ADDRESS 0x10
#define IR_ANGLE_AND_DISTANCE_REGISTER 0x00
#define IR_ANGLE_AND_DISTANCE_BYTES_COUNT 4
#define IR_RAW_REGISTER 0x01
#define IR_RAW_BYTES_COUNT 12
#define IR_SENSOR_COUNT 12
#define IR_NO_SIGNAL 999
#define IR_NO_SIGNAL_ANGLE 180
#define IR_NO_SIGNAL_DISTANCE 0

struct IRData {
  uint16_t angle;
  uint16_t distance;
  uint8_t sensor_IR[IR_SENSOR_COUNT];
};
IRData ir_data = { IR_NO_SIGNAL, 0, { 0 } };


// ========== I2C State Machine ==========
#define I2C_ASYNC_TIMEOUT_MS 4
#define I2C_BNO_RETRY_DEBOUNCE_MS 500
#define I2C_BNO_RESET_DELAY_MS 700
#define I2C_BNO_MODE_SWITCH_DELAY_MS 30

enum AsyncI2CState {
  I2C_STATE_WAIT_FOR_REQUEST = 0,
  I2C_STATE_BNO_CHECK_ID_SET_REGISTER,
  I2C_STATE_BNO_CHECK_ID_READ,
  I2C_STATE_BNO_SET_CONFIG_MODE,
  I2C_STATE_BNO_RESET,
  I2C_STATE_BNO_WAIT_AFTER_RESET,
  I2C_STATE_BNO_WAIT_ID_SET_REGISTER,
  I2C_STATE_BNO_WAIT_ID_READ,
  I2C_STATE_BNO_SET_POWER_MODE,
  I2C_STATE_BNO_SET_PAGE,
  I2C_STATE_BNO_SET_SYS_TRIGGER,
  I2C_STATE_BNO_SET_IMUPLUS_MODE,
  I2C_STATE_BNO_WAIT_AFTER_OP_MODE,
  I2C_STATE_IR_SET_ANGLE_REGISTER,
  I2C_STATE_IR_READ_ANGLE,
  I2C_STATE_IR_SET_RAW_REGISTER,
  I2C_STATE_IR_READ_RAW,
  I2C_STATE_BNO_SET_EULER_REGISTER,
  I2C_STATE_BNO_READ_EULER
};

enum AsyncI2CReadKind {
  I2C_READ_NONE = 0,
  I2C_READ_BNO_ID,
  I2C_READ_IR_ANGLE_DISTANCE,
  I2C_READ_IR_RAW,
  I2C_READ_BNO_EULER
};

AsyncI2CState i2c_state = I2C_STATE_BNO_CHECK_ID_SET_REGISTER;
AsyncI2CState i2c_next_state = I2C_STATE_BNO_CHECK_ID_SET_REGISTER;
AsyncI2CReadKind i2c_read_kind = I2C_READ_NONE;
bool i2c_op_in_progress = false;
unsigned long i2c_op_started_at_ms = 0;
unsigned long i2c_state_started_at_ms = 0;
uint8_t i2c_tx_byte = 0;
uint8_t i2c_tx_buffer[2] = { 0, 0 };
uint8_t bno_chip_id_buffer[1] = { 0 };
uint8_t bno_euler_buffer[6] = { 0 };
uint8_t ir_angle_distance_buffer[IR_ANGLE_AND_DISTANCE_BYTES_COUNT] = { 0 };
uint8_t ir_raw_buffer[IR_RAW_BYTES_COUNT] = { 0 };

bool compass_read_requested = false;
bool compass_read_completed = false;
bool ir_read_requested = false;
bool ir_read_completed = false;


// ========== Line Sensors ==========
#define LINE_SENSOR_COUNT 12
#define LINE_SENSOR_READ_RESOLUTION 12
#define LINE_SENSOR_MIN_VALUE 0
#define LINE_SENSOR_MAX_VALUE ((1 << LINE_SENSOR_READ_RESOLUTION) - 1)

const int line_sensors_pin_config[LINE_SENSOR_COUNT] = {
  23, 22, 21, 20,
  17, 16, 15, 14,
  41, 40, 39, 38,
};

struct LineData {
  uint16_t sensor_line[LINE_SENSOR_COUNT];
  uint16_t sensor_line_min[LINE_SENSOR_COUNT];
  uint16_t sensor_line_max[LINE_SENSOR_COUNT];
};
LineData line_data = { { 0 } };


// ========== Data Collection ==========
struct SensorData {
  MotorsData motors_data;
  CompassData compass_data;
  IRData ir_data;
  LineData line_data;
};

SensorData sensor_data;



// ================================================
// =                 Functions                    =
// ================================================

// ========== Button Functions ==========
bool isButtonPressed(Button &b) {
  int currentReading = digitalRead(b.pin);
  bool clicked = false;
  const unsigned long debounceDelay = 50;

  if (currentReading != b.lastState) {
    b.lastDebounceTime = millis();
  }

  if ((millis() - b.lastDebounceTime) > debounceDelay) {
    if (currentReading == LOW && b.state == HIGH) {
      clicked = true;
    }
    b.state = currentReading;
  }

  b.lastState = currentReading;
  return clicked;
}

// ========== Control State Management ==========
void update_running_state() {
  module_value = bt_module_enabled ? (digitalRead(MODULE_PIN) == HIGH) : true;
  is_running = (main_switch_enabled && module_value);
}

// ========== Debug Functions ==========
void print_sensor_debug_info() {
  // Motor status
  DEBUG_PRINT("Motors: ");
  for (int i = 0; i < MOTOR_COUNT; i++) {
    DEBUG_PRINT("M");
    DEBUG_PRINT(i);
    DEBUG_PRINT("=");
    DEBUG_PRINT(sensor_data.motors_data.motor_speed[i]);
    DEBUG_PRINT(" ");
  }
  DEBUG_PRINT(" | Kicker=");
  DEBUG_PRINTLN(sensor_data.motors_data.kicker_position);

  // Compass orientation
  DEBUG_PRINT("Compass: H=");
  DEBUG_PRINT(sensor_data.compass_data.heading);
  DEBUG_PRINT(" P=");
  DEBUG_PRINT(sensor_data.compass_data.pitch);
  DEBUG_PRINT(" R=");
  DEBUG_PRINTLN(sensor_data.compass_data.roll);

  // IR sensor ball detection
  DEBUG_PRINT("IR Ball: Angle=");
  DEBUG_PRINT(sensor_data.ir_data.angle);
  DEBUG_PRINT(" Dist=");
  DEBUG_PRINT(sensor_data.ir_data.distance);
  DEBUG_PRINT("cm | Sensors: ");
  for (int i = 0; i < IR_SENSOR_COUNT; i++) {
    DEBUG_PRINT(sensor_data.ir_data.sensor_IR[i]);
    DEBUG_PRINT(" ");
  }
  DEBUG_PRINTLN();

  // Line sensors
  DEBUG_PRINT("Line: Min:");
  for (int i = 0; i < LINE_SENSOR_COUNT; i++) {
    DEBUG_PRINT(" ");
    DEBUG_PRINT(sensor_data.line_data.sensor_line_min[i]);
  }
  DEBUG_PRINTLN();
  DEBUG_PRINT("      Max: ");
  for (int i = 0; i < LINE_SENSOR_COUNT; i++) {
    DEBUG_PRINT(sensor_data.line_data.sensor_line_max[i]);
    DEBUG_PRINT(" ");
  }
  DEBUG_PRINTLN();
  DEBUG_PRINTLN("========================================");
}

// ========== Motor Control Functions ==========
void set_motor_speed(int motor_ID, int speed) {
  if (motor_ID < 0 || motor_ID >= MOTOR_COUNT) return;

  int pwm = constrain(abs(speed), 0, 255);
  digitalWrite(motor_pin_config[motor_ID][DIR_INDEX], (speed >= 0) ? HIGH : LOW);
  analogWrite(motor_pin_config[motor_ID][PWM_INDEX], pwm);
}

void set_all_motors_speed(int16_t m_speed[MOTOR_COUNT]) {
  for (int i = 0; i < MOTOR_COUNT; i++) {
    set_motor_speed(i, m_speed[i]);
    motors_data.motor_speed[i] = m_speed[i];
  }
}

void set_kicker_position(int8_t position) {
  position = constrain(position, KICKER_IN, KICKER_OUT);
  digitalWrite(kicker_pin, position);
  motors_data.kicker_position = position;
}

void stop_motors() {
  for (int i = 0; i < MOTOR_COUNT; i++) {
    set_motor_speed(i, MOTOR_STOPPED);
    motors_data.motor_speed[i] = MOTOR_STOPPED;
  }
  set_kicker_position(KICKER_IN);
}

// ========== Sensor Reading Functions ==========
inline void set_compass_invalid() {
  if (bno_initialized) {
    bno_next_retry_at_ms = millis() + (
      i2c_state == I2C_STATE_BNO_SET_EULER_REGISTER ||
      i2c_state == I2C_STATE_BNO_READ_EULER
      ? I2C_BNO_RETRY_DEBOUNCE_MS
      : 0
    );
    bno_initialized = false;
  }

  compass_data.heading = 999;
  compass_data.pitch = 999;
  compass_data.roll = 999;
}

inline void set_ir_no_signal_data() {
  ir_data.angle = IR_NO_SIGNAL;
  ir_data.distance = 0;
  for (int i = 0; i < IR_SENSOR_COUNT; i++) {
    ir_data.sensor_IR[i] = 0;
  }
}

inline void reset_i2c_state_machine() {
  DEBUG_LOG(DEBUG_INFO, "Resetting State Machine");
  i2c_op_in_progress = false;
  i2c_read_kind = I2C_READ_NONE;
  i2c_state = I2C_STATE_WAIT_FOR_REQUEST;
  i2c_next_state = I2C_STATE_WAIT_FOR_REQUEST;
  i2c_state_started_at_ms = 0;
}

inline bool is_bno_state(int state) {
  return state == (int)I2C_STATE_BNO_CHECK_ID_SET_REGISTER ||
         state == (int)I2C_STATE_BNO_CHECK_ID_READ ||
         state == (int)I2C_STATE_BNO_SET_CONFIG_MODE ||
         state == (int)I2C_STATE_BNO_RESET ||
         state == (int)I2C_STATE_BNO_WAIT_AFTER_RESET ||
         state == (int)I2C_STATE_BNO_WAIT_ID_SET_REGISTER ||
         state == (int)I2C_STATE_BNO_WAIT_ID_READ ||
         state == (int)I2C_STATE_BNO_SET_POWER_MODE ||
         state == (int)I2C_STATE_BNO_SET_PAGE ||
         state == (int)I2C_STATE_BNO_SET_SYS_TRIGGER ||
         state == (int)I2C_STATE_BNO_SET_IMUPLUS_MODE ||
         state == (int)I2C_STATE_BNO_WAIT_AFTER_OP_MODE ||
         state == (int)I2C_STATE_BNO_SET_EULER_REGISTER ||
         state == (int)I2C_STATE_BNO_READ_EULER;
}

inline void start_i2c_write(uint8_t address, const uint8_t* buffer, size_t length, bool send_stop, int next_state) {
#if DEBUG_PROFILING_ENABLED
  DEBUG_PROFILING_START(i2c_req_checkpoint);
#endif
  i2c_master.write_async(address, buffer, length, send_stop);
  i2c_op_in_progress = true;
  i2c_read_kind = I2C_READ_NONE;
  i2c_next_state = (AsyncI2CState)next_state;
  i2c_op_started_at_ms = millis();
}

inline void start_i2c_read(uint8_t address, uint8_t* buffer, size_t length, bool send_stop, int read_kind, int next_state) {
#if DEBUG_PROFILING_ENABLED
  DEBUG_PROFILING_START(i2c_req_checkpoint);
#endif
  i2c_master.read_async(address, buffer, length, send_stop);
  i2c_op_in_progress = true;
  i2c_read_kind = (AsyncI2CReadKind)read_kind;
  i2c_next_state = (AsyncI2CState)next_state;
  i2c_op_started_at_ms = millis();
}

inline void request_ir_compass_read() {
  compass_read_requested = true;
  ir_read_requested = true;
  ir_read_completed = false;
  compass_read_completed = false;
}

inline bool are_ir_compass_reads_completed() {
  return ir_read_completed && compass_read_completed;
}

void process_i2c_async() {
#if DEBUG_PROFILING_ENABLED
  unsigned long i2c_start = 0;
  DEBUG_PROFILING_START(i2c_start);

  static unsigned long ir_checkpoint = 0;
  static unsigned long compass_checkpoint = 0;
#endif

  if (i2c_op_in_progress) {
    if (!i2c_master.finished()) {
      if (millis() - i2c_op_started_at_ms > I2C_ASYNC_TIMEOUT_MS) {
        bool is_bno = is_bno_state(i2c_state);
        DEBUG_LOG(DEBUG_ERROR, "Async I2C transaction timeout, read_kind=" + String(i2c_read_kind) + " i2c_state=" + String(i2c_state) + " is_bno=" + String(is_bno));
        if (!is_bno) {
          set_ir_no_signal_data();
        }
        reset_i2c_state_machine();
#if DEBUG_PROFILING_ENABLED
        DEBUG_PROFILING_RECORD(i2c_req_checkpoint, "I2C Request Timeout");
#endif
      }
#if DEBUG_PROFILING_ENABLED
      DEBUG_PROFILING_RECORD(i2c_start, "I2C Update");
#endif
      return;
    }

    i2c_op_in_progress = false;

    if (i2c_master.has_error()) {
      DEBUG_LOG(DEBUG_ERROR, "Async I2C transaction failed, code=" + String((int)i2c_master.error()) + " read_kind=" + String(i2c_read_kind) + " i2c_state=" + String(i2c_state) + " is_bno=" + String(is_bno_state(i2c_state)));
      if (is_bno_state(i2c_state) || i2c_read_kind == I2C_READ_BNO_ID || i2c_read_kind == I2C_READ_BNO_EULER) {
        set_compass_invalid();
      } else {
        set_ir_no_signal_data();
      }
      reset_i2c_state_machine();
#if DEBUG_PROFILING_ENABLED
      DEBUG_PROFILING_RECORD(i2c_start, "I2C Update");
      DEBUG_PROFILING_RECORD(i2c_req_checkpoint, "I2C Request Error");
#endif
      return;
    }
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
void loop() {
#if DEBUG_PROFILING_ENABLED
  unsigned long loop_start = 0;
  DEBUG_PROFILING_START(loop_start);
#endif

  unsigned long current_time = micros();

  fastest_loop();

  static unsigned long last_target_ups_loop_time = 0;
  if (current_time - last_target_ups_loop_time >= INTERVAL_US) {
    last_target_ups_loop_time = current_time;
    target_ups_loop();
  }

#if DEBUG_PROFILING_ENABLED
  DEBUG_PROFILING_RECORD(loop_start, "Main Loop");
  DEBUG_PROFILING_PRINT_IF_READY();
#endif
}

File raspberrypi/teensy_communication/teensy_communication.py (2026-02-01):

import argparse
import json
import logging
import re
import serial
import sys
import time
from dataclasses import dataclass
from serial.tools import list_ports


logger = logging.getLogger("teensy_communication")

DEFAULT_TEENSY_PORT = "/dev/ttyAMA0"
DEFAULT_TEENSY_BAUD = 38400
DEFAULT_TEENSY_TIMEOUT = 1

try:
    from config import MOTOR_COUNT, LINE_SENSOR_COUNT
    EXPECTED_FIELDS = 14 + LINE_SENSOR_COUNT + MOTOR_COUNT
except ImportError:
    MOTOR_COUNT = 4
    EXPECTED_FIELDS = 30

LINE_PATTERN = re.compile(r'^\{\s*"a"\s*=\s*"(?P<data>.*)"\s*\}\s*$')


@dataclass
class CompassData:
    heading: int
    pitch: int
    roll: int

@dataclass
class IRData:
    angle: int
    distance: int
    sensors: list[int]
    status: int

@dataclass
class ParsedTeensyData:
    compass: CompassData
    ir: IRData
    line: list[int]
    raw: str
    timestamp: float


def parse_teensy_line(line: str) -> ParsedTeensyData:
    line = line.strip()
    m = LINE_PATTERN.match(line)
    if not m:
        raise ValueError("Line does not match wrapper {\"a\"=\"...\"}")

    data = m.group("data")
    parts = data.split(",")
    if len(parts) != EXPECTED_FIELDS:
        raise ValueError(f"Wrong number of fields: expected {EXPECTED_FIELDS}, got {len(parts)}")

    try:
        int_parts = [int(p) for p in parts]
        
        parsed = ParsedTeensyData(
            CompassData(
                int_parts[0],
                int_parts[1],
                int_parts[2],
            ),
            IRData(
                int_parts[3],
                int_parts[4],
                int_parts[5:17],
                int_parts[17],
            ),
            int_parts[18:],
            line,
            time.time(),
        )
    except (ValueError, IndexError) as e:
        raise ValueError(f"Failed to parse numeric fields: {e}")

    return parsed


def list_serial_ports() -> list[str]:
    return [p.device for p in list_ports.comports()]


def open_serial(port: str, baud: int = DEFAULT_TEENSY_BAUD, timeout: float = DEFAULT_TEENSY_TIMEOUT) -> serial.Serial:
    try:
        return serial.Serial(port, baudrate=baud, timeout=timeout)
    except serial.SerialException as e:
        ports = list_serial_ports()
        hint = ""
        if ports:
            hint = f" Available ports: {', '.join(ports)}."
        raise RuntimeError(f"Failed to open serial port {port}: {e}.{hint}") from e


def format_message(motor_speeds: list[int], kicker_state: bool) -> str:
    if len(motor_speeds) != MOTOR_COUNT:
        raise ValueError(f"Expected {MOTOR_COUNT} motor speeds, got {len(motor_speeds)}")
    
    formatted_values = []
    for i, speed in enumerate(motor_speeds):
        if not isinstance(speed, (int, float)):
            raise ValueError(f"Motor {i} speed must be numeric, got {type(speed)}")
        clamped = max(-9999, min(9999, int(speed)))
        sign = '+' if clamped >= 0 else '-'
        formatted_values.append(f"{sign}{abs(clamped):04d}")
    
    formatted_values.append('1' if kicker_state else '0')
    data = ",".join(formatted_values)
    return f'{{"a"="{data}"}}'


class TeensyCommunicator:
    def __init__(self, port: str = DEFAULT_TEENSY_PORT, baud: int = DEFAULT_TEENSY_BAUD, timeout: float = DEFAULT_TEENSY_TIMEOUT, auto_connect: bool = True) -> None:
        self.port = port
        self.baud = baud
        self.timeout = timeout
        self.ser = None
        self._log = logging.getLogger(f"teensy_communication.{port}")
        self.buffer: bytearray | None = None
        if auto_connect:
            self.connect()

    def connect(self) -> None:
        if self.ser is not None:
            self._log.warning("Serial port already open")
            return
        self._log.info("Opening serial port %s @ %d", self.port, self.baud)
        self.ser = open_serial(self.port, self.baud, self.timeout)

    def close(self) -> None:
        if self.ser is not None:
            self._log.info("Closing serial port %s", self.port)
            self.ser.close()
            self.ser = None
    
    def __enter__(self) -> "TeensyCommunicator":
        self.connect()
        return self
    
    def __exit__(self, exc_type, exc_val, exc_tb) -> None:
        self.close()
    
    def read_line(self) -> str:
        if self.ser is None:
            raise RuntimeError("Serial port not open. Call connect() first.")
        
        if self.buffer is None:
            self.buffer = bytearray()

        newline_idx = self.buffer.find(b'\n')
        if newline_idx >= 0:
            raw = bytes(self.buffer[:newline_idx + 1])
            self.buffer = self.buffer[newline_idx + 1:]
            try:
                return raw.decode("utf-8", errors="replace").strip()
            except Exception:
                return ""
        
        read_bytes = self.ser.read_all()
        if read_bytes:
            self.buffer.extend(read_bytes)
            newline_idx = self.buffer.find(b'\n')
            if newline_idx >= 0:
                raw = bytes(self.buffer[:newline_idx + 1])
                self.buffer = self.buffer[newline_idx + 1:]
                try:
                    return raw.decode("utf-8", errors="replace").strip()
                except Exception:
                    return ""
        return ""
    
    def read_data(self, timeout: float | None = None) -> ParsedTeensyData | None:
        if self.ser is None:
            raise RuntimeError("Serial port not open. Call connect() first.")
        
        original_timeout = None
        if timeout is not None:
            original_timeout = self.ser.timeout
            self.ser.timeout = timeout
        
        try:
            line = self.read_line()
            if not line:
                return None
            try:
                parsed = parse_teensy_line(line)
                return parsed
            except ValueError as e:
                self._log.warning("Failed to parse line: %s (%s)", line, e)
                return None
        finally:
            if original_timeout is not None:
                self.ser.timeout = original_timeout
    
    def send_message(self, message: str) -> None:
        if self.ser is None:
            raise RuntimeError("Serial port not open. Call connect() first.")
        if not message.endswith('\n'):
            message = message + '\n'
        self.ser.write(message.encode('utf-8'))
    
    def set_motors(self, motor_speeds: list, kicker_state: bool) -> None:
        message = format_message(motor_speeds, kicker_state)
        self.send_message(message)
    
    def stop_motors(self) -> None:
        self.set_motors([0, 0, 0, 0], False)
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

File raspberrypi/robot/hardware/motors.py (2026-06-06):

from __future__ import annotations

import math
import time

from robot import utils, vision
from robot.hardware import line_sensors
from robot.multiprocessing import shared_data
from robot.profiling import profile_function
from robot.config import *



logger = utils.get_logger("Motors Controller")


def calculate_speeds(move_angle_rad: float, move_speed: float, rotate: float) -> list[int]:
    speeds = []
    for motor_angle in MOTOR_LOCATIONS:
        motor_rad = math.radians(motor_angle)
        motor_speed = move_speed * math.cos(move_angle_rad - motor_rad) + rotate
        speeds.append(int(motor_speed))
    return speeds


class MotorsController:
    """Basic motors controller with acceleration smoothing. Takes desired movement commands"""

    def __init__(self):
        self.move_x = 0.0
        self.move_y = 0.0
        self.rotate = 0.0
        self.acceleration = LOGIC_LOOP_FREQUENCY / MOTOR_ACCELERATION_LOGIC_LOOPS

    def set_motors(self, angle: float, speed: float, rotate: float):
        self.move_x += (speed * math.cos(math.radians(angle)) - self.move_x) * self.acceleration * LOGIC_LOOP_PERIOD
        self.move_y += (speed * math.sin(math.radians(angle)) - self.move_y) * self.acceleration * LOGIC_LOOP_PERIOD
        self.rotate += (rotate - self.rotate) * self.acceleration * LOGIC_LOOP_PERIOD

        new_angle = math.atan2(self.move_y, self.move_x)
        speed = math.sqrt(self.move_x**2 + self.move_y**2)

        motors = calculate_speeds(new_angle, speed * 255, self.rotate * 255)
        shared_data.set_motor_speeds(motors)
    
    def reset(self):
        self.move_x = 0.0
        self.move_y = 0.0
        self.rotate = 0.0
        shared_data.set_motor_speeds([0, 0, 0, 0])


class SmartMotorsController(MotorsController):
    """
    Enhanced motors controller with:
        - Rotation correction: when enabled, automatically applies a rotation correction to maintain the robot's heading when no manual rotation input is given.
        - Line avoidance: when enabled, detects line sensor triggers and automatically steers the robot away from the line for a short duration, with cooldown to prevent oscillation.
        - Position-based speed: when enabled, uses the robot's position estimate to reduce speed as it approaches lines, to help prevent crossing them.
    """

    def __init__(self):
        super().__init__()
        self.target_heading = None
        self.rotation_deadzone = 15.0
        self.rotation_correction_gain = 1.0
        
        self.line_avoidance_active = False
        self.line_avoidance_direction = 0.0
        self.line_avoidance_start_time = 0.0
        self.line_avoidance_min_duration = 0.5
        self.line_avoidance_cooldown_duration = 0.5
        self.last_line_avoid_end_time = 0.0
        self.recently_crossed_angles = []

        self.rotation_correction_enabled = True
        self.line_avoiding_enabled = True
        self.position_based_speed_enabled = True

    @profile_function
    def set_motors(self, angle: float, speed: float, rotate: float):
        hardware_data = shared_data.get_hardware_compass_ir()
        current_heading = hardware_data[0] if hardware_data[0] != 999.0 else None

        rotation_correction_enabled = shared_data.get_rotation_correction_enabled() and self.rotation_correction_enabled

        absolute_angle = (angle + self.target_heading - current_heading) % 360 if rotation_correction_enabled and self.target_heading is not None and current_heading is not None else angle
        self.move_x += (speed * math.cos(math.radians(absolute_angle)) - self.move_x) * self.acceleration * LOGIC_LOOP_PERIOD
        self.move_y += (speed * math.sin(math.radians(absolute_angle)) - self.move_y) * self.acceleration * LOGIC_LOOP_PERIOD
        self.rotate += (rotate - self.rotate) * self.acceleration * LOGIC_LOOP_PERIOD
        move_angle = math.atan2(self.move_y, self.move_x)
        move_speed = math.sqrt(self.move_x**2 + self.move_y**2)

        rotation_correction = 0.0
        if rotation_correction_enabled:
            if abs(self.rotate) > 0.01:
                self.target_heading = None
            elif self.target_heading is None and current_heading is not None:
                self.target_heading = current_heading
            if current_heading is not None and self.target_heading is not None:
                heading_error = (self.target_heading - current_heading + 180) % 360 - 180
                if abs(heading_error) > self.rotation_deadzone:
                    rotation_correction = (heading_error / 180.0) * self.rotation_correction_gain

        total_rotation = self.rotate * 0.4 + rotation_correction
        total_rotation = max(-1.0, min(1.0, total_rotation))
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

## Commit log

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2025-12-18 Rework teensy code
    - Rename variables, definitions and functions to more logical names
    - Remove unnecessary comments
    - Add DEBUG definition to toggle debug printing
    - Add DEBUG_SERIAL and RASPBERRRY_SERIAL definitions to easily change the serials
    [teensy.ino]
2025-12-19 created board for teensy
    created sketch of board for teensy, in future it should be made in some program for it, right now it should be everything
    [Teensy_board.xlsx]
2025-12-19 3d moel of driver bracket
    For now the best version of motor driver's bracket, driver should sit in it and it should be whole screwd up on other parts of construchtion.
    ATENTION: This part can not be made out of any conductive or semiconductive material, while it has no protection on it - there is possibility to connect GND and 12V!!!
    [Driver_bracket.stl]
2025-12-20 adding 3d model of robot for OpenSCAD
    this is the last version of robot model for now
    [Robot.scad]
2025-12-20 Update and rename hardware/Robot.scad to hardware/3d design/Robot.scad
    making project more transparent
    [Robot.scad]
2025-12-20 Rename hardware/Driver_bracket.stl to hardware/3d design/Driver_bracket.stl
    moving files on right place
    [Driver_bracket.stl]
2025-12-20 adding parts of robot in .stl format
    adding files, which do not require OpenSCAD installed, and can be used
    [Ball_zone.stl, Wall.stl]
2025-12-20 Update and rename Robot.scad to _Robot.scad
    file will be always on top, if ordered alphabeticly
    [_Robot.scad]
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2025-12-21 uploading 3d model of robot
    newest version of robot, added everything
    [Driver_bracket.scad, Motor_brackets.scad, Raspberry_bracket.scad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]
2025-12-21 uploading .stl files for better accesibility
    uploading also .stl files, because .scad is not openable, unless you hev OpenSCAD
    [ball_zone.stl, bottom_part.stl, driver_bracket.stl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]
2025-12-21 Rename hardware/3D design/ball_zone.stl to hardware/3D design/stl/ball_zone.stl
    moving to better place
    [ball_zone.stl]
2025-12-21 Rename hardware/3D design/bottom_part.stl to hardware/3D design/stl/bottom_part.stl
    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
    [bottom_part.stl]
2025-12-21 Rename hardware/3D design/driver_bracket.stl to hardware/3D design/stl/driver_bracket.stl
    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
    [driver_bracket.stl]
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2025-12-21 Rename hardware/3D design/middle_wall.stl to hardware/3D design/stl/middle_wall.stl
    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
    [middle_wall.stl]
2025-12-21 Rename hardware/3D design/raspberry_bracket.stl to hardware/3D design/stl/raspberry_bracket.stl
    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
    [raspberry_bracket.stl]
2025-12-21 Rename hardware/3D design/whole_bottom_wall.stl to hardware/3D design/stl/whole_bottom_wall.stl
    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
    [whole_bottom_wall.stl]
2025-12-21 uploading new versio of pcb
    new version of pcb whith teensy
    [Teensy_board.xlsx]
2025-12-22 added kicker to program
    from this version, teensy can use kicker, and to message from raspberry is added one number, new version of message: {"a"="-0000,-0000,-0000,-0000,0"} where 0 can be replaced by any number and - can be replaced whith + , changing the last number between values 1 and 9 does not make sense, ot is just a logic high / low
    [teensy.ino]
2025-12-22 uploading new robot parts
    newest version of all robot parts, also txt file whith documentacion
    [ball_zone.stl, bottom_part.stl, kicker_cutout.stl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]
2025-12-22 Update and rename Motor_brackets.scad to Motor_bracket.scad
    using better name, more consisten of othor files
    [Motor_bracket.scad]
2025-12-22 adding .scad files of robot
    this is the latest version of robot, from last update there have been several changes
    [Driver_bracket.scad, Kicker.scad, Motor_bracket.scad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]
2025-12-22 new version of pcb
    adding new version of pcb, also in csv format
    [Teensy_board.csv, Teensy_board.xlsx]
2025-12-23 uploading files in scad and stl format v 23-12
    uploading files of 3d model of robot, only missing part from now is camera bracket
    [Camera_bracket.scad, IR_sensor_bracket.scad, IR_sensor_bracket.stl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]
2025-12-23 camera bracket and holder are created
    new thing, camera bracket and camera holder
    camera bracket - conects to camera and to camera bracket holder
    camera holder conects camera bracket whith camera to construction
    [Camera_bracket.scad, camera_bracket.stl, camera_bracket_holder.stl]
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2025-12-27 Fix debug prints
2026-01-15 files for 18x18 printer
    version of robot in 18x18
    [B0310.stl, Camera_bracket.scad, Driver_bracket.scad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]
2026-01-20 adding line sensor place
    adding line sensor place to model, motors will be mounted from top
    [Motor_bracket.scad, Robot.scad, bottom_part.stl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]
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2026-01-24 added line sensor place
    this is the first model whith space for line sensor
    [Level_shifter.scad, Robot.scad, bottom_part.stl]
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2026-01-25 added buttons to program
    added buttons, one for on/off, second for use/not use bluetooth module. only missing part of program is line
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2026-01-30 Fix teensy_communication.py
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2026-01-31 Rework python scripts to use multiprocessing instead of threading
    [camera.py, helpers.py, teensy_communication.py]
2026-02-01 Fix teensy message parsing
    [teensy.ino, teensy_communication.py]
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2026-02-02 Fix error when running teensy_communication.py in shell
    [teensy_communication.py]
2026-02-02 Fix message sending from raspberry pi to teensy
    [teensy.ino]
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2026-02-08 Rework line sensor calibration
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2026-02-23 ball zone modification
    adding ball zone whithout kicker cutout space/hole
    [ball_zone_no_kicker.stl]
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2026-03-01 Improve motors rotation correction
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2026-03-12 Fix bugs and errors
    [hardware_process.py]
2026-03-14 Remove unnescessary includes and add sketch.yaml
    - Remove unused <string.h> and <algorithm> includes
    - Add sketch.yaml with the default FQBN set to teensy:avr:teensy41 for
    usage with the arduino-cli
    - Rename BNO055_ID to BNO055_SENSOR_ID to avoid compilation warnings
    [teensy.ino]
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2026-03-20 Rework autonomous controller so it supports mutliple state machines
    [goal.py, hardware_process.py]
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2026-04-06 Rework ball & goal color detection/calibration to support multiple HSV ranges
    [ball.py, camera_processing_process.py, goal.py]
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2026-04-15 Fix head north setting in autonomous mode
    [motors.py, soccer.py]
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2026-04-27 Add flipped raspberry pi bracket
    [raspberry_bracket_flipped.scad, raspberry_bracket_flipped.stl]
2026-04-27 Improve line avoiding on back goal line
    [soccer.py]
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2026-05-02 Fix control buttons in teensy.ino
    [teensy.ino]
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2026-05-02 Fix async I2C compass issues
    [teensy.ino]
2026-05-02 adding back camera
    back camera was added to upper part and midle wall
    [Robot.scad, middle_wall.stl, uppre_part.stl]
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2026-05-02 back camera repositioned to center
    everything deleted, but added display and rpi buttons holes
    [Robot.scad, middle_wall.stl, uppre_part.stl]
2026-05-06 Rework command parsing in teensy.ino
    [teensy.ino]
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2026-05-11 changed handle bracket
    handle bracket space for handle is now smaller
    [Robot.scad, handle_bracket.stl]
2026-05-11 added uppest part
    added bradn new part of robot
    [Robot.scad, handle.stl, uppest_part.stl]
2026-05-11 optimising
    few components were optimised, for better look or functionality
    [Robot.scad, handle_bracket.stl, upper_part.stl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]
2026-05-11 edited handle brackets
    made handle brackets better - screws are now going always from front (last vesrion: left screws have gone from back, right screws have gone from front)
    [Camera_bracket.scad, Robot.scad, handle.stl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]
2026-05-12 Fix IR angle extracting
    [teensy.py]
2026-05-12 bigger hole
    hole is now big enough for handle
    [Robot.scad, uppest_part.stl]
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2026-05-12 ir sensor is now lower
    short screws => lower ir sensor
    [Robot.scad, uppest_part_new.stl]
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2026-05-14 Rework uppest_part module
    [Robot.scad, uppest_part.stl, uppest_part_new.stl]
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2026-05-18 Fix wheel parameters
    [Kicker.scad, Wheels.scad]
2026-05-18 Fix bottom part wheel cutout
    [Robot.scad]
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2026-05-18 Fix bottom part motor holes
    [Motor_bracket.scad, Robot.scad, bottom_part.stl]
2026-05-19 Rework openscad code
    [B0310.stl, Camera_bracket.scad, Driver_bracket.scad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]
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2026-05-19 Fix openscad modules to work with FreeCAD import
    [ball_zone.scad, middle_part.scad, robot.scad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]
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2026-05-31 Fix own goal detection glitch
    [camera_processing_process.py]
2026-05-31 Fix goal tracking rotation in goalkeeper
    [soccer.py]
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2026-06-02 Fix goalkeeper and bluetooth role sync logic
    [soccer.py]
2026-06-02 Improve line avoiding and position based speed
    [motors.py, soccer.py]
2026-06-05 Fix teensy not sending blutooth module updates
    [teensy.ino]
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
